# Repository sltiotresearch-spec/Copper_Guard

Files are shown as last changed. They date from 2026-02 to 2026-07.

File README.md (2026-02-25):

# 🛡️Copper_Guard
Copper Guard is an IoT-based copper cable protection system that detects wire cuts or failures and instantly sends SMS and call alerts using ESP12F (ESP8266) and SIM800C GSM module.

When a wire is cut or disabled:
- 📩 An SMS alert is sent
- 📞 A phone call notification is triggered

The system evolved through four hardware versions, improving scalability, connectivity, and reliability.

---

## 🚀 Versions Overview

| Version | Image | Wires Supported | Board Type | Connectivity | Deployment |
|---|---|---|---|---|---|
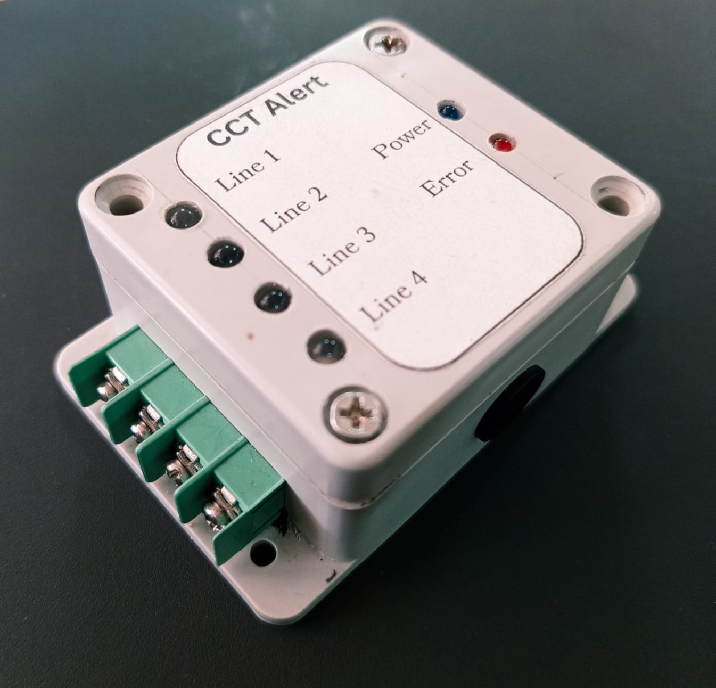
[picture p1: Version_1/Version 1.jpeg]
| Version 1 |  | 4 | STEM Board | GSM | Prototype |
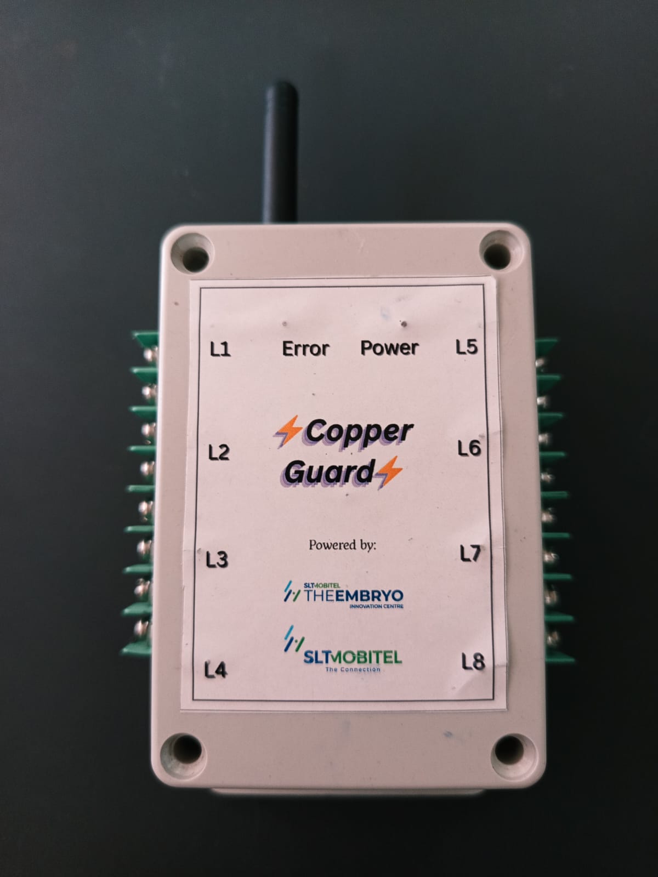
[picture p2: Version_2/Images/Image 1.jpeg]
| Version 2 |  | 8 | ESP Board | GSM + WiFi | 5 devices |
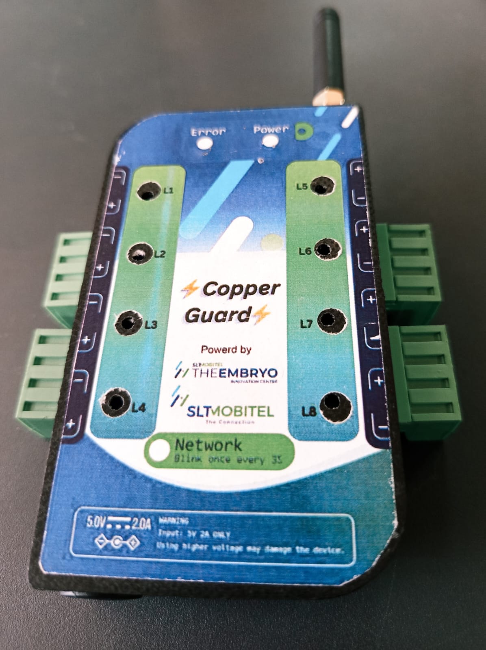
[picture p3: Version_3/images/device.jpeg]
| Version 3 |  | 8 | Custom PCB | GSM + WiFi | Improved |
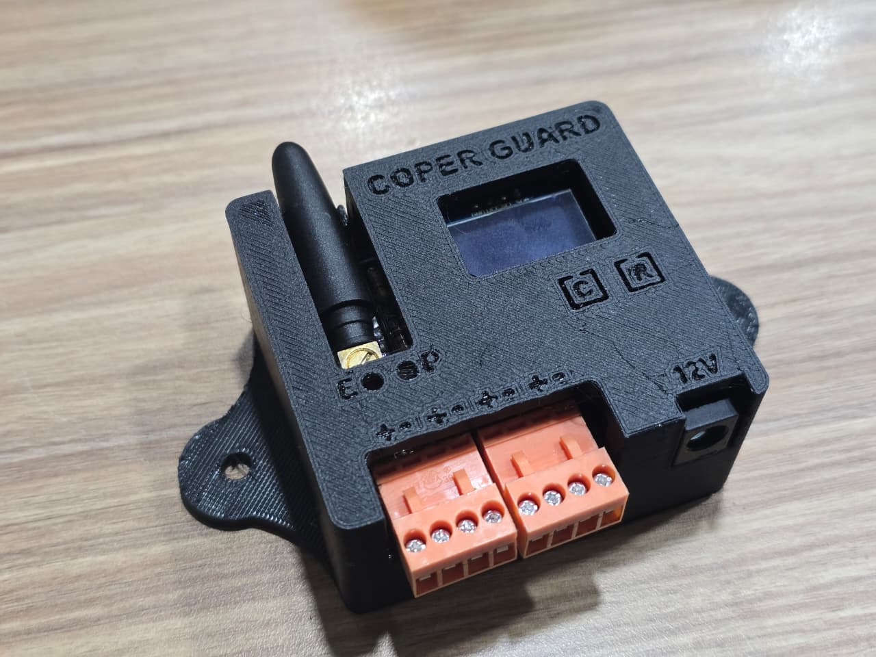
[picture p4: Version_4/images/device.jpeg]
| Version 4 |  | 4 | Custom PCB + ESP12F | GSM + WiFi + OLED | Junction |
---

## 🔧 System Features

- Wire cut detection using optocouplers
- SMS and Call alert system
- GSM communication module
- Buck converter power regulation
- WiFi connectivity (ESP versions)
- OLED display (Version 4)

---

## 📂 Branch Structure

Each version is maintained in a separate branch:

- `version1`
- `version2`
- `version3`
- `version4`

Each branch contains:
- Source code
- PCB design files
- Schematics
- Photos
- Documentation

---

## 📍 Deployment

Version 2 devices are currently deployed in the Ratnapura district.

---

## 👨‍💻 Author

Developed as part of Copper Guard Project.

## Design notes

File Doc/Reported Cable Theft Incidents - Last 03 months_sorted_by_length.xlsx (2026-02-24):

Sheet: Sheet2
Row Labels | Count of LEA | Sum of Length (m)
BIA | 22 | 892
GQ | 22 | 1391
VR | 18 | 1172
KOM | 18 | 1260
RN | 14 | 1013
AW | 10 | 500
MGM | 10 | 1130
KY | 10 | 440
KWL | 10 | 1925
AD | 9 | 472
MNG | 9 | 1225
VG | 8 | 835
MAL | 8 | 401
KT | 8 | 640
BG | 7 | 795
PUG | 7 | 370
MLT | 6 | 1850
DJ | 6 | 950
KDW | 6 | 305
AB | 6 | 573
DX | 6 | 387
PW | 5 | 600
WJ | 5 | 335
KEL | 5 | 450
PK | 5 | 300
BW | 5 | 360
KLY | 4 | 205
PNG | 4 | 320
GIR | 4 | 245
KDY | 3 | 595
GE | 3 | 300
HO | 3 | 386
KAL | 3 | 220
MI | 3 | 555
KR | 2 | 250
KWA | 2 | 342
PE | 2 | 150
RG | 2 | 52
PL | 2 | 155
SL | 2 | 150
GLG | 2 | 185
JL | 2 | 12
RAM | 2 | 260
KDL | 2 | 180
RM | 2 | 170
MMU | 2 | 192
UDT | 2 | 180
DGD | 2
GP | 2 | 160
NC | 2 | 130
EH | 2 | 98
WT | 2 | 20
HZ | 1 | 230
RKL | 1 | 80
GU | 1 | 80
KWN | 1 | 200
DI | 1 | 200
AG | 1
MX | 1 | 245
KG | 1 | 50
RK | 1 | 100
PTR | 1 | 20
AK | 1 | 50
WP | 1 | 200
MNA | 1 | 100
KJ | 1 | 120
MWI | 1 | 30
HAR | 1 | 680
KE | 1 | 70
HEY | 1 | 65
RGM | 1 | 50
DG | 1 | 80
MH | 1 | 150
(blank) |  | 1833
Grand Total | 329 | 30716

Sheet: Sheet1
Region | Province | OPMC | LEA | Incident Date (m,d) | Location | Length (m)
REGION 01 | CP | KY | KY | 2024-11-30 | Gamunu Mawatha Jnc, Hanthana | 15
METRO | METRO 02 | RM | RM | 2025-01-01 | Maha Vihara Rd, Moratuwa | 20
REGION 02 | SP | MH | WJ | 2025-01-03 | Sathyahettige mawatha - Weligama | 160
REGION 01 | WPN | NTB | VG | 2025-01-05 | Eksath Mawatha Marapola Nywala | 200
REGION 02 | SP | MH | AK | 2025-01-05 | Near Athuraliya Maha Vidyalaya ground, Akuressa rd, Athuraliya | 50
REGION 01 | WPN | NTB | KDY | 2025-01-06 | Kotadeniyawa Walpita Farm Road | 200
REGION 02 | WPS | KT | MGM | 2025-01-06 | Peragas junction, Pelawatta Rd | 160
REGION 02 | SAB & UVA | KE | GLG | 2025-01-06 | Nelundeniya Allauwa Road | 140
REGION 02 | SP | MH | WJ | 2025-01-06 | Warakapitiya-Welihinda road 500m before the junction to CBL(munchee) warehouse . | 100
REGION 02 | WPS | KT | MGM | 2025-01-07 | Malwathukanda Road, Horawala | 150
REGION 02 | WPS | KT | MGM | 2025-01-07 | Malwathukanda Road, Horawala | 150
REGION 02 | SP | MH | KJ | 2025-01-08 | Near the Archeology Office on Kamburupitiya - Kadduwa Road | 120
REGION 01 | WPN | NG | MNG | 2025-01-10 | Aluthapola, Minuwangoda | 150
REGION 01 | WPN | KI | MAL | 2025-01-10 | Ulahitiwala | 70
REGION 01 | WPN | NTB | VG | 2025-01-13 | Balabowa Sadun uyana Road (Balabowa Ambalama) | 160
REGION 01 | WPN | NG | MNG | 2025-01-17 | Develapola, Minuwangoda | 150
METRO | METRO 02 | HO | KOM | 2025-01-18 | Meegahawatta Rd, Kanampella,Kosgama | 31
REGION 02 | WPS | KT | KT | 2025-01-20 | Meneri Thenna Road near Saw mill | 500
REGION 02 | SAB & UVA | RN | KEL | 2025-01-20 | Kiriella - Madala | 120
REGION 02 | SAB & UVA | RN | BG | 2025-01-25 | Balangoda,Amupitiya Near Mamalgaha Juntion | 250
REGION 02 | WPS | KT | MGM | 2025-01-25 | Delgas junction, Madawala Road | 231
REGION 01 | WPN | NTB | KDY | 2025-01-25 | Kotadeniyawa Walpita Farm Road | 180
REGION 02 | SAB & UVA | KE | MNA | 2025-01-25 | Daswaththa | 100
REGION 02 | SAB & UVA | RN | KEL | 2025-01-28 | Kiriella-Madala | 150
REGION 01 | NWP | KLY | PL | 2025-01-29 | Paragammana - Ingaradawla Road - infront of Dummalapitiya watta | 75
REGION 01 | WPN | GQ | GQ | 2025-01-30 | Balummahara Junction Miriswatta, Gampaha | 95
REGION 01 | WPN | GQ | GQ | 2025-02-01 | Balummahara Junction Miriswatta, Gampaha | 75
REGION 01 | WPN | GQ | GE | 2025-02-02 | Kothalawala mw | 110
REGION 01 | WPN | GQ | GE | 2025-02-02 | Kothalawala mw | 100
REGION 01 | WPN | NG | MNG | 2025-02-02 | Galoluwa | 65
REGION 01 | WPN | GQ | GQ | 2025-02-04 | Balummahara Junction Miriswatta, Gampaha | 50
REGION 01 | NWP | KG | AB | 2025-02-05 | Narammala Road,Maharachchimulla./Humbuluwa Alawwa | 120
REGION 01 | NWP | KG | AB | 2025-02-05 | Narammala Road,Maharachchimulla./Humbuluwa Alawwa | 80
REGION 01 | WPN | KI | VR | 2025-02-05 | Ahugammana | 45
REGION 01 | WPN | NG | MNG | 2025-02-06 | Yakahatuwa | 300
REGION 01 | WPN | GQ | GQ | 2025-02-06 | Balummahara Junction Miriswatta, Gampaha | 50
REGION 02 | SAB & UVA | KE | RK | 2025-02-07 | Thaldawa- Rambukkana | 100
REGION 01 | WPN | GQ | GE | 2025-02-07 | Rajasinghe mw | 90
REGION 02 | WPS | KT | MGM | 2025-02-08 | Kalupahana road Peragas junction. | 90
REGION 01 | WPN | KI | VR | 2025-02-08 | Maharagama | 50
REGION 02 | WPS | KT | MGM | 2025-02-09 | Pelawaththa road Peragas junction. | 95
REGION 01 | WPN | GQ | GQ | 2025-02-10 | Balummahara Junction Miriswatta, Gampaha | 50
REGION 01 | WPN | KI | MAL | 2025-02-13 | Wewa pARA, Mapitigama | 120
REGION 01 | WPN | KI | VR | 2025-02-13 | Danawkanda rd Kirikittha | 87
REGION 01 | WPN | KI | MAL | 2025-02-13 | Kanukatiya | 60
REGION 01 | NWP | KG | AB | 2025-02-14 | COLOMBO RD,KAPUWARALA,ALAWWA. | 98
REGION 01 | NWP | KG | PW | 2025-02-14 | WADAKADA RD,UDAPOLA,POLGAHAWELA. | 80
REGION 01 | NWP | KG | PW | 2025-02-14 | WADAKADA RD,UDAPOLA,POLGAHAWELA. | 80
METRO | METRO 02 | HO | KOM | 2025-02-15 | Pahathgama Junction | 130
REGION 01 | NWP | KG | AB | 2025-02-16 | HITHTHARAPOLA,MAHARACHCHIMULLA,ALAWWA. | 85
REGION 01 | WPN | NG | DJ | 2025-02-21 | Niwala road Wewagedara | 130
REGION 01 | NWP | KG | PW | 2025-02-21 | Narammala Road,udapola & Narammala Road, Wadakada,Polgahawela | 120
REGION 01 | NWP | KLY | PL | 2025-02-21 | Werahara Road , Yakwila - infront of wewa | 80
REGION 01 | NWP | KG | PW | 2025-02-21 | Narammala Road,udapola & Narammala Road, Wadakada,Polgahawela | 80
REGION 01 | NWP | KG | AB | 2025-02-21 | Giriulla Road,7 mile post,paramaulla,Alawwa. | 40
REGION 01 | WPN | KI | KDW | 2025-02-22 | Mankda Paara | 60
REGION 01 | WPN | NG | DJ | 2025-02-25 | Hirikuluwa road Badalgama | 270
REGION 01 | WPN | NTB | MI | 2025-02-25 | Bothele Madagama Adupe Road | 150
REGION 01 | WPN | KI | KDW | 2025-02-27 | Mankda Paara | 60
REGION 01 | WPN | KI | KDW | 2025-02-27 | Mankda Paara | 60
REGION 03 | EP | VA | MMU | 2025-02-27 | Mamaduwa main road | 50
REGION 02 | SAB & UVA | RN | BG | 2025-03-01 | Imbulpe | 80
REGION 01 | WPN | NTB | VG | 2025-03-02 | Dadagamuwa Temple Road Veyangoda | 220
REGION 03 | NP | VA | MMU | 2025-03-03 | Mamaduwa main road | 142
REGION 01 | NWP | KLY | KLY | 2025-03-04 | Narangalla - Wadugedara rd (near to paddy fied ) | 75
REGION 01 | NWP | KLY | KLY | 2025-03-04 | Narangalla - Wadugedara rd (near to paddy fied ) | 75
REGION 02 | SAB & UVA | RN | BG | 2025-03-04 | Rassagala Road | 60
REGION 01 | NWP | KLY | KLY | 2025-03-04 | Hettipola rd - Hediyamulla ( Near to Helabojunhala) | 40
REGION 01 | NWP | KLY | KLY | 2025-03-04 | Hettipola rd - Hediyamulla ( Near to Helabojunhala) | 15
REGION 01 | WPN | NTB | MI | 2025-03-05 | Warakapola road Thalagama | 270
REGION 01 | NWP | CW | MX | 2025-03-11 | Uraliya-Panirendawa Road, Sembukattiya | 245
REGION 01 | WPN | KI | VR | 2025-03-11 | Batahena Kanatta near Kirikitta Road | 20
REGION 01 | WPN | KI | VR | 2025-03-11 | Batahena Kanatta near Kirikitta Road | 20
REGION 01 | WPN | KI | VR | 2025-03-11 | Batahena Kanatta near Kirikitta Road | 20
REGION 01 | WPN | NTB | KAL | 2025-03-13 | Galamuna Hapitigama Kaleliya | 70
REGION 01 | WPN | NTB | KAL | 2025-03-16 | Galamuna Hapitigama Kaleliya | 40
REGION 03 | NP | AD | KWA | 2025-03-18 | Madatugama A9 road | 196
REGION 01 | WPN | WT | WT | 2025-03-18 | Bangalawatta road, Wattala | 10
REGION 01 | WPN | WT | WT | 2025-03-18 | Bangalawatta road, Wattala | 10
REGION 01 | WPN | KI | VR | 2025-03-19 | Godagedara temple Road ,Balummahara | 105
REGION 01 | WPN | KI | VR | 2025-03-19 | Godagedara temple Road ,Balummahara | 105
REGION 03 | NP | AD | MWI | 2025-03-19 | Issinbessagala, Medawachchiya | 30
REGION 01 | NWP | KLY | HZ | 2025-03-22 | Hettipola moragolla - near to moragolla wewa | 230
REGION 03 | NP | AD | KWA | 2025-03-22 | Madatugama A9 road | 146
METRO | METRO 01 | KX | KDL | 2025-03-22 | Near jalthara Tile factory | 100
REGION 01 | WPN | NTB | VG | 2025-03-23 | Magalegoda Bemmulla Road | 40
REGION 01 | WPN | NTB | VG | 2025-03-24 | Magalegoda Bemmulla Road | 70
REGION 01 | CP | GP | GP | 2025-03-25 | Dolsabage Road,Sinhapitiya | 80
METRO | METRO 02 | HO | KOM | 2025-03-25 | Kaluaggala Labugama Rd, Near transformer | 50
REGION 01 | WPN | KI | BIA | 2025-03-27 | Dekatana Jambugas Handiya | 40
REGION 01 | WPN | KI | BIA | 2025-03-27 | Dekatana Jambugas Handiya | 40
Region 01 | WPN | NTB | VG | 2025-03-29 | Keenawala Koshena watta road | 60
Region 01 | WPN | NTB | KDY | 2025-03-31 | Kotadeniyawa Walpita Farm Road | 215
REGION 01 | CP | GP | GP | 2025-04-01 | Mawathura, Gampola | 80
REGION 01 | WPN | KI | BIA | 2025-04-02 | Pattihandiya near bridge | 3
Region 01 | WPN | WT | JL | 2025-04-03 | Kristhraja Mawatha, Thudalla, JaELA | 6
REGION 01 | WPN | KI | BIA | 2025-04-05 | Kelaniya OPMC | 64
REGION 01 | WPN | NG | DJ | 2025-04-06 | Ethiliyagala Road, Balagalla | 200
REGION 02 | SAB & UVA | RN | BG | 2025-04-06 | Kirimatitenna near Senaka Pole Yard | 175
REGION 01 | WPN | NG | DJ | 2025-04-06 | Ethiliyagala Road, Balagalla (4 core fiber cable) | 150
REGION 02 | SAB & UVA | RN | BG | 2025-04-06 | Meddekanda - Rassagala Road | 80
REGION 02 | SAB & UVA | RN | BG | 2025-04-06 | Vikiliya, Kalthota road near Ape Kade Hardware in Balangoda | 70
REGION 01 | WPN | WT | RG | 2025-04-06 | Prison Rd, Samagi Mawatha.Ragama | 40
REGION 01 | WPN | KI | KWL | 2025-04-07 | Meethirigala | 85
REGION 01 | WPN | GQ | GQ | 2025-04-07 | Grama sanwardhena mw, Oruthota | 80
REGION 01 | WPN | GQ | UDT | 2025-04-09 | Kahatowita | 80
REGION 01 | WPN | KI | BIA | 2025-04-09 | Kanukatiya | 60
Region 01 | WPN | NTB | MI | 2025-04-12 | Idiparape Road Mirigama | 135
REGION 01 | WPN | KI | BIA | 2025-04-12 | Mapiltigama | 70
REGION 01 | WPN | KI | BIA | 2025-04-12 | Near Ambalama | 60
REGION 01 | WPN | KI | BIA | 2025-04-14 | Putupagala | 70
REGION 02 | SAB & UVA | RN | BG | 2025-04-15 | Weligepola road at Damahana in Balangoda | 80
REGION 02 | SAB & UVA | RN | KEL | 2025-04-17 | Kurugammodara,Heraniyawaka-Matuwagala bus hlt | 40
METRO | METRO 02 | HO | PNG | 2025-04-19 |  | 25
REGION 02 | SAB & UVA | RN | EH | 2025-04-23 | Cable theft at Minnana area | 58
REGION 01 | WPN | KI | BIA | 2025-04-27 | Putupagala | 80
REGION 01 | NWP | KLY | GU | 2025-04-29 | Haddamulla junction Giriulla | 80
REGION 01 | WPN | NG | MNG | 2025-04-30 | Mathammana Walawwa Road | 150
REGION 01 | WPN | NG | MNG | 2025-04-30 | Mathammana Walawwa Road | 150
REGION 01 | WPN | NG | MNG | 2025-04-30 | Mathammana Walawwa Road | 150
Region 01 | WPN | NTB | VG | 2025-05-02 | Mahavita Junction Yakkala | 35
REGION 02 | SAB & UVA | RN | RN | 2025-05-03 | Cable Theft at Thiriwanaketiya Juntion | 100
REGION 01 | WPN | KI | BIA | 2025-05-10 | Pidaliwatta | 85
REGION 02 | SAB & UVA | RN | RN | 2025-05-14 | Cable theft at Malwala Road - Dimbulvitiya | 250
METRO | METRO 02 | RM | RM | 2025-05-15 | Angulana, Saumya Pedesa | 150
REGION 02 | SAB & UVA | RN | PE | 2025-05-15 | Sannasgama Pelmadulla | 120
REGION 02 | SP | MH | MH | 2025-05-17 | Near Rassandeniya Juntion,Dondra | 150
REGION 02 | SAB & UVA | RN |  | 2025-05-17 | Nivithigala Watapotha Road Ambalandeniya case-1 | 120
REGION 01 | WPN | KI | BIA | 2025-05-17 | Putupagala | 100
REGION 02 | SAB & UVA | RN | KR | 2025-05-19 | Kuruwita Eratne Road | 150
REGION 01 | WPN | KI | BIA | 2025-05-21 | Putupagala | 80
REGION 02 | SAB & UVA | RN |  | 2025-05-21 | Nivithigala Watapotha Road Ambalandeniya case-2 | 40
REGION 02 | SAB & UVA | RN | EH | 2025-05-21 | Minnana Near Wikasitha Garage | 40
REGION 02 | SAB & UVA | RN | RN | 2025-05-23 | Cable theft incident at Thiriwanaketiya Juntion | 50
REGION 02 | SAB & UVA | RN | RN | 2025-05-24 | Gonakumbura Road | 150
REGION 02 | SAB & UVA | RN |  | 2025-05-24 | Nivithigala Watapotha Road Ambalandeniya case-3 | 120
Region 01 | WPN | NTB | KAL | 2025-05-25 | Kukulnape Road Pallewela | 110
METRO | METRO 02 | HO | KOM | 2025-05-25 | Labugama Rd | 25
METRO | METRO 02 | HO | KOM | 2025-05-25 | Labugama Rd | 25
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

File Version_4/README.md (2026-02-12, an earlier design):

# 🛡️ Copper Guard – Version 4

> Optimized 4-Channel Monitoring System  
> Integrated PCB Design | GSM + WiFi + OLED

---

## 📌 Overview

Copper Guard Version 4 is the optimized and refined version of the system, designed specifically for 4-way cross road installations.

Unlike previous versions supporting 8 wires, Version 4 is intentionally limited to 4 wires, as a standard 4-way junction requires monitoring of only four copper lines.

This version integrates the ESP12F chip directly onto a custom PCB and includes an OLED display for real-time system status monitoring.

---

## 🚀 Key Improvements Over Version 3

- Optimized from 8 wires → 4 wires (junction-specific design)
- Integrated **ESP12F chip** directly on PCB
- Added **OLED display** for live system feedback
- Cleaner and more compact PCB layout
- Dedicated GSM board with antenna
- Reduced hardware complexity

---

## 🔧 Hardware Components

- 📡 GSM Board with Antenna
- 🌐 ESP12F WiFi Chip (Integrated on PCB)
- 🔌 4 Optocouplers
- ⚡ Buck Converter
- 🖥 OLED Display
- 🖨 Custom Designed PCB

---

## ⚙️ System Specifications

| Feature | Description |
|---|---|
| Wire Capacity | 4 Wires |
| Communication | GSM + WiFi |
| Alert System | SMS + Phone Call |
| Display | OLED Status Display |
| Power Regulation | Buck Converter |
| Isolation Method | Optocouplers |
| Design Type | Fully Integrated Custom PCB |

---

## 🧠 Working Principle

1. Each of the 4 copper lines is connected through an optocoupler for isolation.
2. The ESP12F continuously monitors line status.
3. If a wire is cut or disabled:
   - 📩 SMS alert is sent via GSM module
   - 📞 Phone call notification is triggered
4. The OLED display shows:
   - Line status
   - System state
   - Connectivity information
5. WiFi connectivity allows future IoT expansion or monitoring.

---

## 📂 Folder Structure
````
version4
│
├── firmware
│ ├── main.ino
│ └── libraries.txt
│
├── hardware
│ ├── schematic.pdf
│ ├── pcb_layout.pdf
│ └── gerber_files
│
├── Images
│ ├── pcb_top.jpg
│ ├── pcb_bottom.jpg
│ ├── assembled_unit.jpg
│ └── oled_display.jpg
│
└── README.md
````
---

## 📡 Communication Architecture
````
Copper Wire Inputs (4 Lines)
│
▼
Optocouplers (Isolation Stage)
│
▼
ESP12F (Main Controller)
│
├──► GSM Board
│ ├── SMS Alert
│ └── Phone Call Alert
│
├──► OLED Display
│ └── Real-Time Status Display
│
└──► WiFi Network
└── Remote Monitoring (Optional)
````
---

## 🌍 Deployment Design Context

Version 4 is designed specifically for:

- 4-way road junction installations
- Compact field deployment
- Reduced hardware overhead
- Improved maintainability

Since a standard 4-way cross road only requires monitoring of 4 copper lines, supporting 8 wires is unnecessary.  
Version 4 removes excess complexity while improving integration.

---

## ⚠️ Limitations

- Limited to 4 wire inputs (junction-specific)
- Requires stable GSM signal for reliable alerting
- WiFi functionality depends on network availability

---

## 🔮 System Evolution Summary

| Version | Key Change |
|---|---|
| V1 | Basic GSM prototype (4 wires) |
| V2 | Expanded to 8 wires + WiFi |
| V3 | Custom PCB implementation |
| V4 | Integrated ESP12F + OLED + Optimized 4-wire design |

---

## 🛠 Installation Overview

1. Connect 4 copper lines to input terminals.
2. Power the system through regulated supply.
3. Insert configured SIM card into GSM board.
4. Configure alert numbers in firmware.
5. Verify OLED display for system status.
6. Test by simulating wire disconnection.

---

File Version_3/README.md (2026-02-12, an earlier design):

# 🛡️ Copper Guard – Version 3

> 8-Channel Copper Wire Monitoring System  
> Custom PCB Implementation | GSM + WiFi Enabled

---

## 📌 Overview

Copper Guard Version 3 is an improved hardware refinement of Version 2.

The core functionality remains the same:
- 8 wire monitoring
- GSM alert system
- WiFi connectivity via ESP board

The major improvement in Version 3 is the transition from a dot board assembly to a custom-designed PCB, significantly improving reliability, structure, and maintainability.

---

## 🚀 Improvements Over Version 2

- Replaced dot board with **custom PCB**
- Reduced wiring complexity
- Improved circuit stability
- Better mechanical strength
- Cleaner and more professional hardware layout

---

## 🔧 Hardware Components

- 📡 GSM Module
- 🌐 ESP Board (WiFi enabled)
- 🔌 8 Optocouplers
- ⚡ Buck Converter
- 📶 External Antenna
- 🖥 Custom Designed PCB

---

## ⚙️ System Specifications

| Feature | Description |
|---|---|
| Wire Capacity | 8 Wires |
| Communication | GSM + WiFi |
| Alert System | SMS + Phone Call |
| Power Regulation | Buck Converter |
| Isolation Method | Optocouplers |
| Board Type | Custom PCB |

---

## 🧠 Working Principle

1. Each copper wire line is connected through an optocoupler.
2. The ESP board continuously monitors the status of all 8 lines.
3. If a wire is cut or disabled:
   - 📩 The GSM module sends an SMS alert
   - 📞 A phone call notification is triggered
4. WiFi connectivity allows remote monitoring or IoT expansion.

---

## 📂 Folder Structure
````
version3
│
├── firmware
│ ├── main.ino
│ └── libraries.txt
│
├── hardware
│ ├── schematic.png
│ └── gerber_files
│
├── Images
│ └── device.jpeg
│
└── README.md
````
---

## 📡 Communication Architecture
````
Copper Wire Inputs (8 Lines)
│
▼
Optocouplers (Isolation Stage)
│
▼
ESP Board (Controller)
│
├──► GSM Module
│ ├── SMS Alert
│ └── Phone Call Alert
│
└──► WiFi Network
└── Remote Monitoring (Optional)
````
---

## 🌍 Deployment Context

Version 3 represents the transition from prototype-level hardware to a more production-ready design.

The use of a custom PCB:
- Improves long-term durability
- Simplifies assembly
- Reduces electrical noise
- Enhances maintainability

---

## ⚠️ Limitations

- Requires stable GSM signal for reliable alerting
- Depends on WiFi availability for remote monitoring
- Still limited to 8 wire inputs

---

## 🔮 Evolution Path

Version 3 paved the way for:
- Integrated ESP12F chip on PCB (Version 4)
- OLED status display
- Optimized 4-wire configuration for junction installations

---

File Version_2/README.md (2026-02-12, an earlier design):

# 🛡️ Copper Guard – Version 2

> Expanded 8-Channel Copper Wire Monitoring System  
> GSM + WiFi Enabled | Field Deployed Model

---

## 📌 Overview

Copper Guard Version 2 is an improved and expanded version of the original copper wire monitoring system.

This version:
- Increases wire capacity  
- Introduces WiFi connectivity  
- Improves system flexibility using an ESP-based board  

📍 **Five devices are currently deployed in the Ratnapura District.**

---

## 🚀 Key Improvements from Version 1

- Increased wire capacity from **4 → 8**
- Replaced STEM board with **ESP board**
- Added **WiFi connectivity**
- Improved scalability
- Field deployment of **5 devices**
- Dot board implementation for component connections

---

## 🔧 Hardware Components

- 📡 GSM Module (for SMS and Call alerts)
- 🌐 ESP Board (WiFi enabled)
- 🔌 8 Optocouplers (for wire monitoring)
- ⚡ Buck Converter (Voltage regulation)
- 📶 External Antenna
- 🧩 Dot Board (Prototype board assembly)

---

## ⚙️ System Specifications

| Feature | Description |
|---|---|
| Wire Capacity | 8 Wires |
| Communication | GSM + WiFi |
| Alert System | SMS + Phone Call |
| Power Regulation | Buck Converter |
| Isolation Method | Optocouplers |
| Deployment | 5 Active Units |

---

## 🧠 Working Principle

1. Each copper wire line is connected through an optocoupler.  
2. The ESP board continuously monitors the status of all 8 lines.  
3. If a wire is cut or disabled:
   - 📩 The GSM module sends an SMS alert  
   - 📞 A phone call notification is triggered  
4. WiFi connectivity allows remote monitoring or future IoT integration.

---

## 📂 Folder Structure
````
version2
│
├── firmware
│ ├── main.ino
│ └── libraries.txt
│
├── Images
│ ├── Image 1.jpeg
│ ├── Image 2.jpeg
│ └── Image 3.jpeg
│
└── README.md

````
---

## 📡 Communication Architecture
````
Wire Input
↓
Optocoupler
↓
ESP Board
├── GSM Module → SMS + Call
└── WiFi Network → Remote Monitoring (Optional)

````
---

## 🌍 Deployment Information

- **Location:** Ratnapura District  
- **Units Installed:** 5  
- **Environment:** Roadside / Field installations  
- **Status:** Operational  

---

## ⚠️ Limitations

- Built using dot board (not custom PCB)
- Manual assembly increases wiring complexity
- Requires stable GSM signal for reliable alerting

---

## 🔮 Future Improvements (Implemented in Later Versions)

- Custom PCB design (Version 3)
- Integrated ESP12F chip on PCB (Version 4)
- OLED status display (Version 4)
- Optimized wire capacity for junction-based installations

---

## 🛠 Installation Overview

1. Connect 8 copper lines to input terminals.  
2. Power the system via regulated supply (through buck converter).  
3. Insert configured SIM card into GSM module.  
4. Connect ESP to WiFi network (if remote monitoring required).  
5. Configure alert phone numbers in firmware.  
6. Deploy and test by simulating wire disconnection.

---

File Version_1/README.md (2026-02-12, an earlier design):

# Copper Guard - Version 1

## 📌 Overview
Version 1 is the initial prototype of Copper Guard.

## 🔧 Hardware Components

- GSM Module
- 4 Optocouplers
- Buck Converter
- STEM Board
- DIP Switch
- PCB Type Antenna

## ⚙️ Features

- Supports 4 wire connections
- DIP switch to enable/disable wires
- SMS and Call alert system
- GSM-based communication

## ⚠️ Limitations

- SIM number must be changed when DIP switch configuration changes
- Only one device built

## 📂 Folder Structure

- firmware → Arduino code
- hardware → Schematics and PCB
- images → Device images
- documentation → System explanation

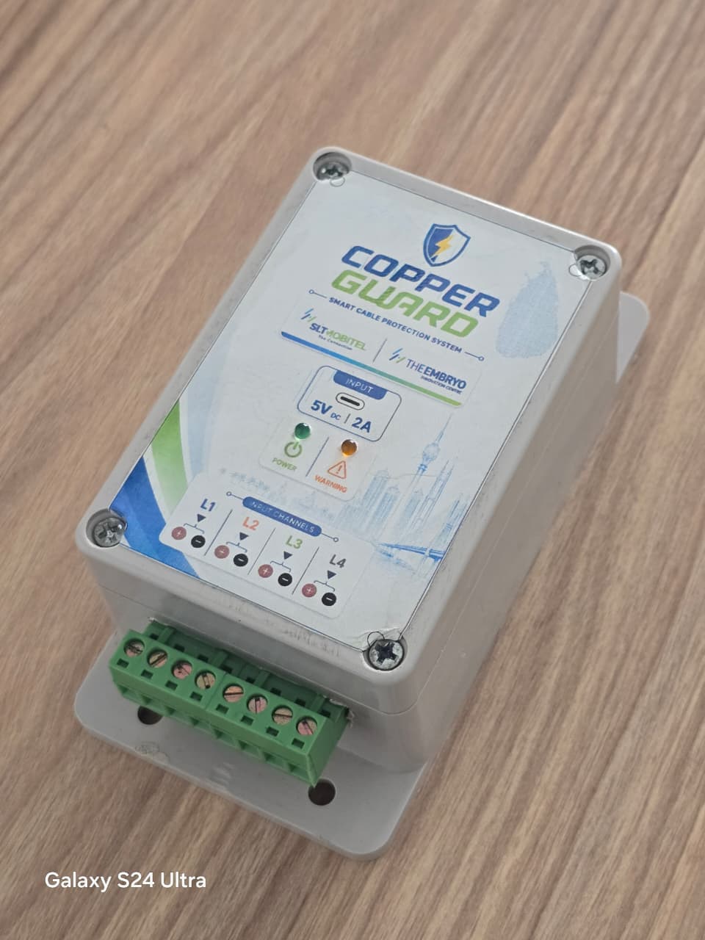
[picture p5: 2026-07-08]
Version_5/Images/WhatsApp Image 2026-06-15 at 12.03.02 PM.jpeg

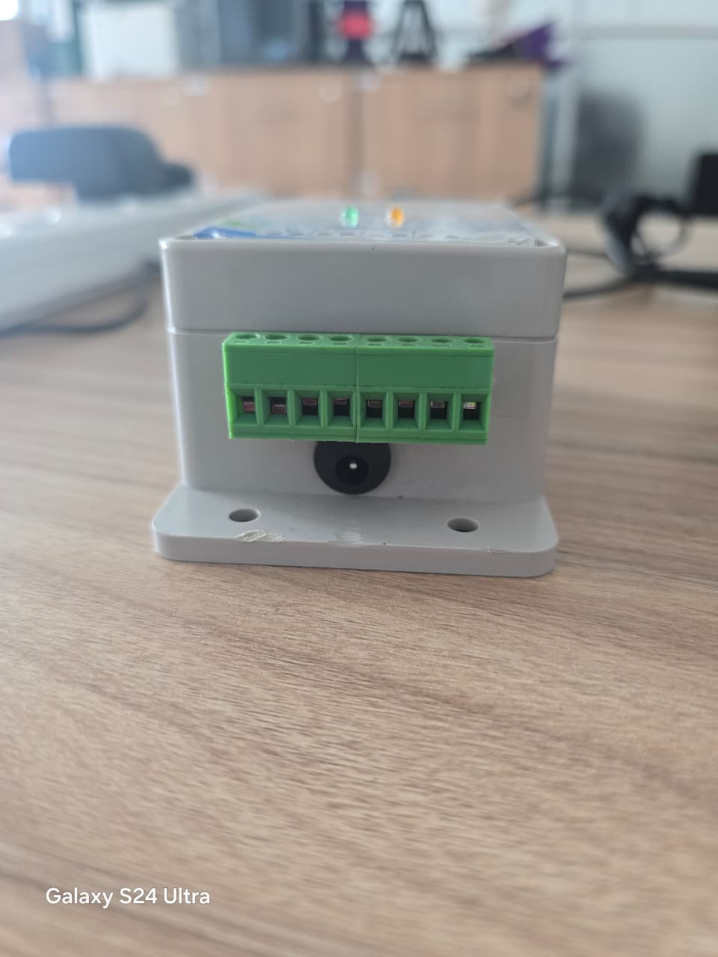
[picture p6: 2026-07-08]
Version_5/Images/WhatsApp Image 2026-06-15 at 12.05.35 PM.jpeg

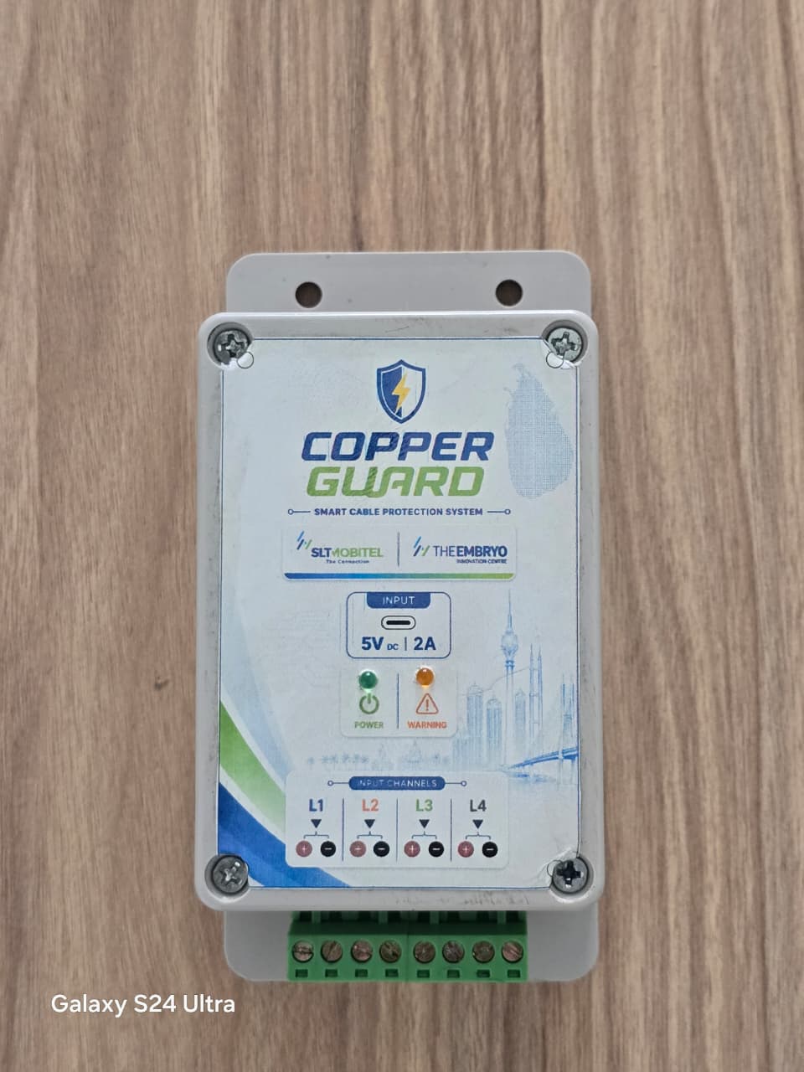
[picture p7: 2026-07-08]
Version_5/Images/WhatsApp Image 2026-06-15 at 12.03.03 PM.jpeg

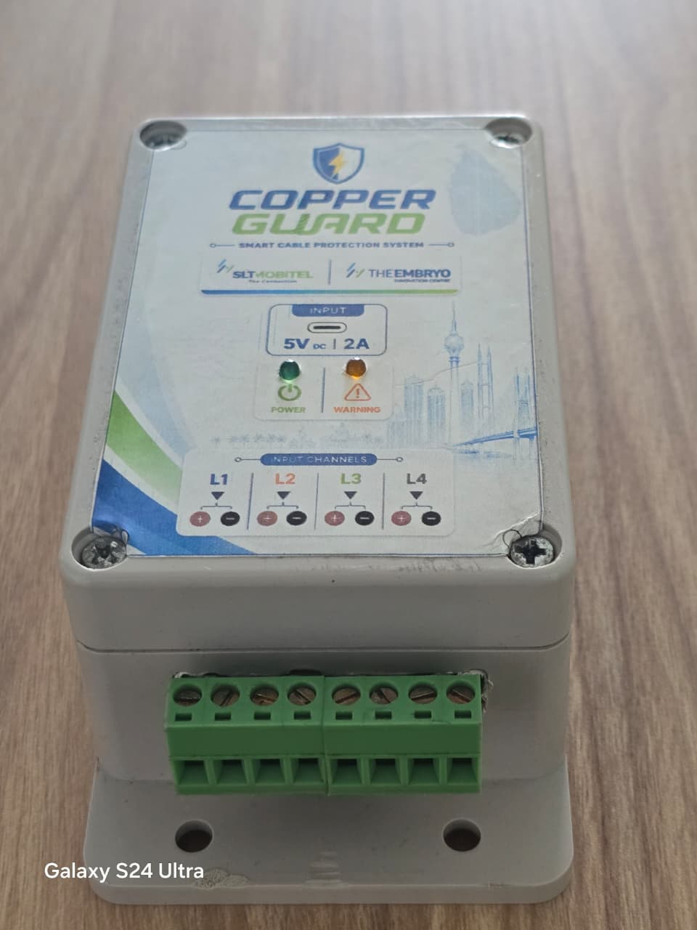
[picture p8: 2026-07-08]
Version_5/Images/WhatsApp Image 2026-06-15 at 12.03.04 PM.jpeg

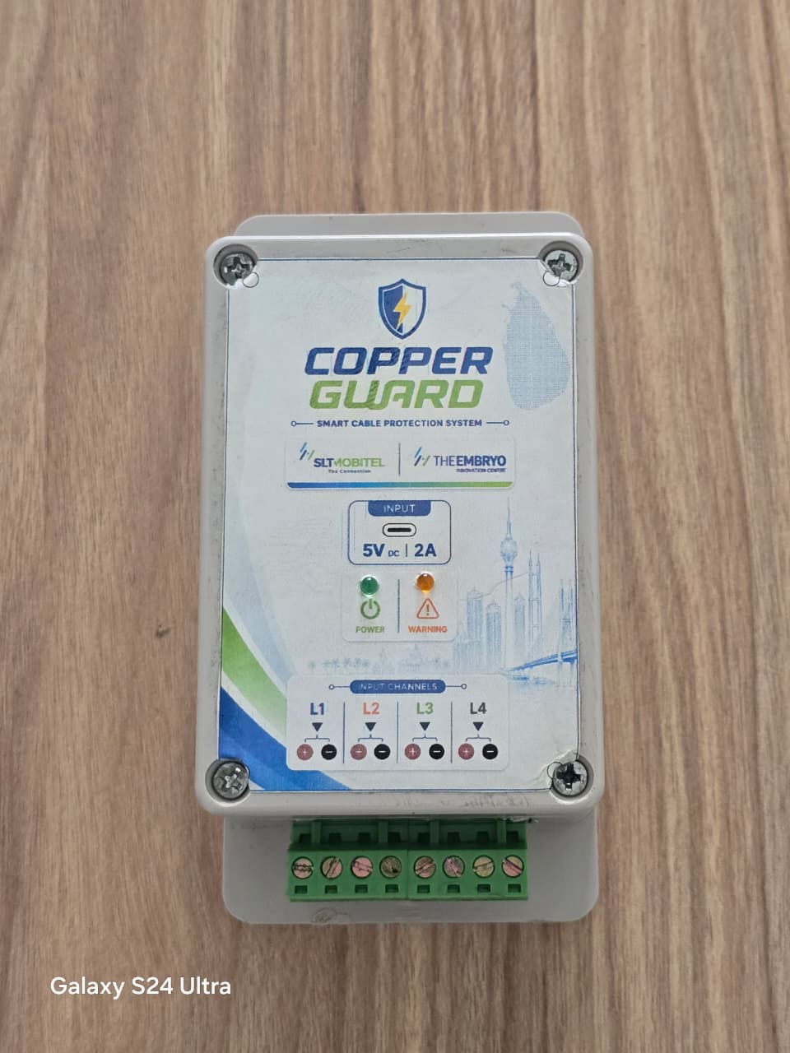
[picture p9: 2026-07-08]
Version_5/Images/WhatsApp Image 2026-06-15 at 12.03.00 PM.jpeg

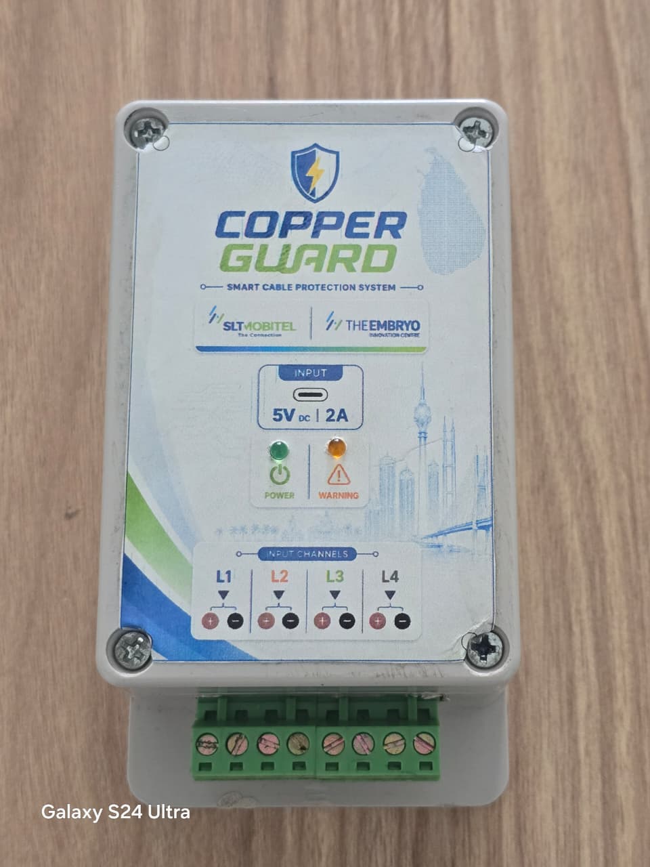
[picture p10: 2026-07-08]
Version_5/Images/WhatsApp Image 2026-06-15 at 12.03.01 PM.jpeg

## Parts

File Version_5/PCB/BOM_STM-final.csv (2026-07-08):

ID | Name | Designator | Footprint | Quantity | Manufacturer Part | Manufacturer | Supplier | Supplier Part | Price
1 | 4.7kΩ | R1,R2,R3,R4 | R2512 | 4 | 25121WJ0472T4E | UNI-ROYAL(厚声) | LCSC | C33178 | 0.023
2 | 3.3kΩ | R5,R6,R7,R8 | R1210 | 4 | RC1210FR-073K3L | YAGEO(国巨) | LCSC | C83146 | 0.025
3 | B2B-PH-K-S(LF)(SN) | CN1 | CONN-TH_B2B-PH-K-S | 1 | B2B-PH-K-S(LF)(SN) | JST | LCSC | C131337 | 0.035
4 | B8B-PH-K-S-(LF)(SN) | U1 | CONN-TH_B8B-PH-K-S-LF-SN | 1 | B8B-PH-K-S(LF)(SN) | JST | LCSC | C157974 | 0.096
5 | B4B-PH-K-S-(LF)(SN) | U3,U4 | CONN-TH_B4B-PH-K-S-LF-SN | 2 | B4B-PH-K-S-(LF)(SN) | JST Sales America | LCSC | C160257
6 | Header-Female-2.54_1x10 | J1,J2 | HDR-TH_10P-P2.54-V-F | 2 | 2.54-1*10P母 | BOOMELE(博穆精密) | LCSC | C35445 | 0.107
7 | ic socket 16 pin | OPTOCOUPLER | DIP-16_L20.3-W10.2-P2.54-LS7.6-BL | 1 | X5621FV-2x08-C762D7430 | XKB Connectivity(中国星坤) | LCSC | C2684758 | 0.526
8 | 10kΩ | R9,R10 | R1206 | 2 | 1206W4J0103T5E | UNI-ROYAL(厚声) | LCSC | C1489 | 0.006

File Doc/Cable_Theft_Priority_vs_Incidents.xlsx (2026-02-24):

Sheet: Priority_vs_Incidents
OPMC | Priority Node | Mapped LEA (base) | Incidents in last 3 months (same OPMC & LEA) | Total stolen length (m) | Max single incident length (m) | First incident date | Last incident date
KE | MNA-DSW-NODE | MNA | 1 | 100 | 100 | 2025-01-25 | 2025-01-25
KE | MNA-KPP-NODE | MNA | 1 | 100 | 100 | 2025-01-25 | 2025-01-25
RN | BG-IBP-NODE | BG | 7 | 795 | 250 | 2025-01-25 | 2025-04-15
RN | RN-GKB-NODE | RN | 14 | 1013 | 250 | 2025-05-03 | 2025-11-06
BD | BD-WRP-NODE | BD | 0 | 0
BD | MM-LNG-NODE | MM | 0 | 0

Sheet: Matched_Incidents
Region | Province | OPMC | LEA | Incident Date (m,d) | Location | Copper Cable Type | Unnamed: 7 | Length (m) | GPS (From) | GPS (To) | Police Entry No. | Reported Date (mm/dd/yyyy) | No of affected Customers | Failure Duration(hours) | Estimated Value of Stolen Cables (LKR) | Cost of Replacemnt (LKR) | WO Status | Unnamed: 18 | Unnamed: 19 | Unnamed: 20 | Matched priority nodes
REGION 02 | SAB & UVA | RN | BG | 2025-01-25 | Balangoda,Amupitiya Near Mamalgaha Juntion | Aerial | 0.9MM/50PR | 250 | 6.678343 80.736550 | 6.680223 80.737630 | MOIB 65/50 |  |  |  | 191304.2 |  | SAP81193 | 2025-01-27 | 2025-09-30 | Approved | BG-IBP-NODE
REGION 02 | SAB & UVA | RN | RN | 2025-05-14 | Cable theft at Malwala Road - Dimbulvitiya | Aerial | 0.5MM/100PR | 250 | 6.715561 80.441674 | 6.714161 80.440535 | GCIB (1) 82/124 | 2025-05-14 |  |  | 663474.12 |  | SAP83921 | 2025-05-19 |  | Approved | RN-GKB-NODE
REGION 02 | SAB & UVA | RN | BG | 2025-04-06 | Kirimatitenna near Senaka Pole Yard | Aerial | 0.65MM/150PR | 175 | 6.630489, 80.728140 | 6.630113, 80.729701 | MOIB 180/59 | 2025-04-07 |  |  | 301237.03 |  | SAP83326 | 2025-04-19 |  | Approved | BG-IBP-NODE
REGION 02 | SAB & UVA | RN | RN | 2025-05-24 | Gonakumbura Road | Aerial | 0.5MM/100PR | 150 | 6.6720506 80.4651694 | 6.6709664 80.4661813 | GCIB (02) 138/225 | 2025-05-24 |  |  | 403883.27 |  | SAP84116 | 2025-05-28 |  | Approved | RN-GKB-NODE
REGION 02 | SAB & UVA | RN | RN | 2025-06-19 | Malwala Road Incident - 2 | Aerial | 0.5MM/100PR | 112 | 6.73085 80.43520 | 6.73152 80.43516 | MOIB 258/67 | 2025-06-20 |  |  | 303194.46 |  | SAP84912 | 2025-06-25 |  | Approved | RN-GKB-NODE
REGION 02 | SAB & UVA | KE | MNA | 2025-01-25 | Daswaththa | Aerial | 0.5MM/10PR | 100 | 7.223274,80.441287 |  | GCIB 63/556 |  |  |  | 120784.83 |  | SAP82072 | 2025-02-27 |  | Approved | MNA-DSW-NODE, MNA-KPP-NODE
REGION 02 | SAB & UVA | RN | RN | 2025-05-03 | Cable Theft at Thiriwanaketiya Juntion | Aerial | 0.5MM/150PR | 100 | 6.665665 80.431985 | 6.665542 80.432909 | GCIB(02)354/36 | 2025-05-04 |  |  | 281212.61 |  | SAP83822 | 2025-05-15 |  | Approved | RN-GKB-NODE
REGION 02 | SAB & UVA | RN | RN | 2025-06-19 | Malwala Road Incident - 1 | Aerial | 0.5MM/100PR | 91 | 6.72519 80.43947 | 6.72462 80.44000 | GCIB C(1) 106/232 | 2025-06-20 |  |  | 245508.44 |  | SAP84909 | 2025-06-25 |  | Approved | RN-GKB-NODE
REGION 02 | SAB & UVA | RN | BG | 2025-04-15 | Weligepola road at Damahana in Balangoda | Aerial | 0.9MM/50PR | 80 | 6.608817 80.736963 | 6.609219 80.737105 | MOIB 370/208 | 2025-04-22 |  |  | 144333.49 |  | SAP83393 | 2025-04-22 |  | Approved | BG-IBP-NODE
REGION 02 | SAB & UVA | RN | BG | 2025-04-06 | Meddekanda - Rassagala Road | Aerial | 0.65MM/50PR | 80 | 6.676198, 80.671349 | 6.676199, 80.671342 | MOIB 179/58 | 2025-04-07 |  |  | 134542.26 |  | SAP83311 | 2025-04-17 |  | Approved | BG-IBP-NODE
REGION 02 | SAB & UVA | RN | BG | 2025-03-01 | Imbulpe | Aerial | 0.9MM/50PR | 80 | 6.678343 80.736550 | 6.680223 80.737630 | MOIB 171/57 | 410961 |  |  | 161304.25 |  | SAP82221 | 2025-03-04 | 2025-09-30 | Approved | BG-IBP-NODE
REGION 02 | SAB & UVA | RN | BG | 2025-04-06 | Vikiliya, Kalthota road near Ape Kade Hardware in Balangoda | Aerial | 0.65MM/30PR | 70 | 6.624958, 80.741966 | 6.625300, 80.742509 | MOIB 220/90 | 2025-04-09 |  |  | 98347.02 |  | SAP83327 | 2025-04-19 |  | Approved | BG-IBP-NODE
REGION 02 | SAB & UVA | RN | BG | 2025-03-04 | Rassagala Road | Aerial | 0.65MM/100PR | 60 | 6.661998 80.692571 | 6.662205, 80.692181 | MOIB 214/35 | 2025-03-04 |  |  | 160963.17 |  | SAP82249 | 2025-03-04 | 2025-09-30 | Approved | BG-IBP-NODE
REGION 02 | SAB & UVA | RN | RN | 2025-05-27 | Berenduwa Road | Aerial | 0.65MM/100PR | 50 | 6.663714 80.483289 | 6.63399 80.482976 | GCIB (1) 204/198 | 2025-05-27 |  |  | 132123.1 |  | SAP84119 | 2025-05-28 |  | Approved | RN-GKB-NODE
REGION 02 | SAB & UVA | RN | RN | 2025-05-23 | Cable theft incident at Thiriwanaketiya Juntion | Aerial | 0.5MM/150PR | 50 | 6.665640 80.431484 | 6.665886 80.431077 | GCIB (2) 129/211 | 2025-05-23 |  |  | 165957.36 |  | SAP84010 | 2025-05-23 |  | Approved | RN-GKB-NODE
REGION 02 | SAB & UVA | RN | RN | 2025-06-21 | Thiriwanaketiya Juntion | Aerial | 0.5MM/80PR | 50 | 6.66571 80.43214 | 6.665551 80.4330264 | G(1) 152/283 | 2025-06-25 |  |  | 76158.76 |  | SAP84918 | 2025-06-25 |  | Approved | RN-GKB-NODE
REGION 02 | SAB & UVA | RN | RN | 2025-06-19 | Thiriwanaketiya Juntion | Aerial | 0.5MM/80PR | 50 | 6.665690, 80.432608 | 6.66571 80.43214 | GCIB(2) 107/220 | 2025-06-19 | 50 |  | 54549.32 |  | SAP84888 | 2025-06-24 |  | Approved | RN-GKB-NODE
REGION 02 | SAB & UVA | RN | RN | 2025-09-19 | Marapana,R'pura | Aerial | 0.9MM/50PR | 40 | 6.6516 80.4427 | 6.65188 80.4423 | P (1) 96/144 | 2025-09-22 |  |  | 111035.01 |  | SAP87329 | 2025-09-24 |  | Approved | RN-GKB-NODE
REGION 02 | SAB & UVA | RN | RN | 2025-09-02 | RN~PN Road Near 65/3 Culvert | Aerial | 0.5MM/100PR | 40 | 6.696011 80.375849 | 6.696064 80.375409 | P(3) 19/26 | 2025-09-03 |  |  | Rs.132,286.61 |  | SAP86811 | 2025-09-04 |  | Approved | RN-GKB-NODE
REGION 02 | SAB & UVA | RN | RN | 2025-11-06 | karangoda Juntion Ratnapura | Aerial | 0.5MM/100PR | 30 | 6.6640 80.3811 | 6.663723 80.380853 | MOIB 289/27 | 2025-11-08 |  |  | 131616.21 |  | SAP88800 | 2025-11-11 |  | Approved | RN-GKB-NODE
REGION 02 | SAB & UVA | RN | RN | 2025-05-20 | Thiriwanaketiya~Kalawana Road near bridge around 200m | Aerial | 0.5MM/150PR |  | 6.662266 80.433554 | 6.662266 80.433554 | P(6) 23/89 | 2025-05-20 |  |  | 28532.2 |  | SAP84009 | 2025-05-23 |  | Approved | RN-GKB-NODE
REGION 02 | SAB & UVA | RN | RN | 2025-07-13 | Pelwadiya,Ratnapura | Aerial |  |  | 6.663785, 80.446460 | Same | P-01 233/139.13.05 | 2025-07-14 |  |  | 55604.12 |  | SAP85480 | 2025-07-15 |  | Approved | RN-GKB-NODE

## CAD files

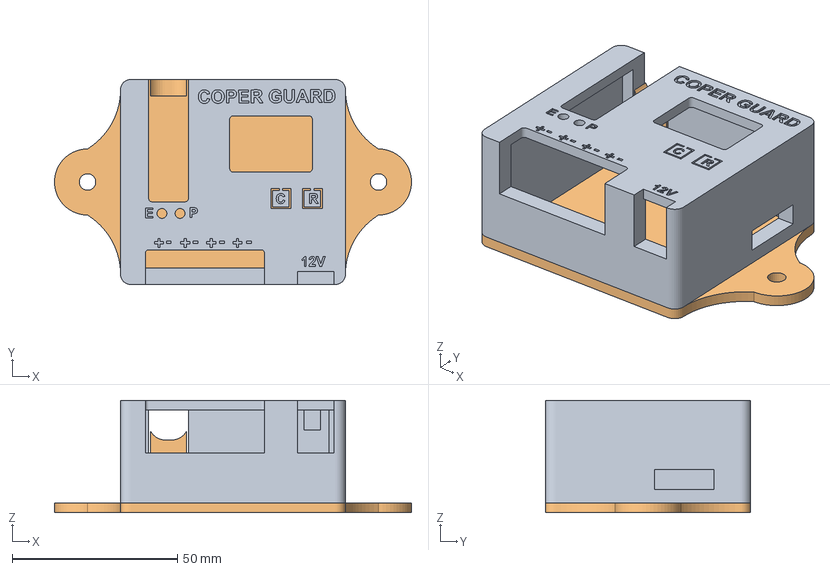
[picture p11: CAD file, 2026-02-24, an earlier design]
Version_4/3D_model/v4_new.3mf
108.0 x 62.0 x 34.0 mm

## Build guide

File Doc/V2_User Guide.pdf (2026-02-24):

# User Manual

# Copper Guard

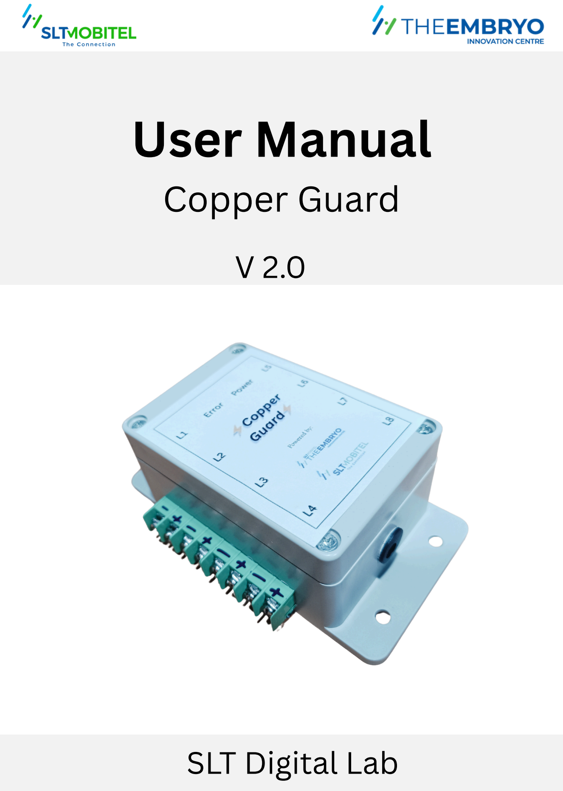
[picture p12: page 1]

# SLT Digital Lab

V 2.0

## Introduction

## Package Contents

## Device Overview

## Installation Instructions

## Configuration and Setup

## Operation

## Maintenance and Troubleshooting

## Safety Information

## Warranty and Support

## Technical Specifications

# Table of Contents

----------------------------------------- 01

--------------------------------- 02

--------------------------------- 03

------------------------- 04

------------------------- 05

------------------------- 06

-------------- 07

------------- 08

----------------------------- 09

--------------------------- 10

# Introduction

## The CopperGuard is a compact, IoT-based copper cable theft alerting device designed to monitor up to 8 copper power lines carrying 48V DC. Built with an ESP32 microcontroller, 8 optocoupler channels, a SIM800L GSM module, and a 3A buck converter, the device continuously

checks the integrity of each monitored line.

If any line is cut or tampered with, CopperGuard immediately sends an SMS alert to preconfigured mobile numbers, helping facility managers or utility providers respond quickly and prevent loss or downtime. The device is powered by a stable 5V 2A input and connects easily using screw terminal blocks for secure and reliable

installation.

## CopperGuard is ideal for applications such as telecom towers, solar farms, street lighting systems, and industrial

setups where copper theft can cause serious disruption.

# Package Contents

## Copper Guard Device

## Power Adapter

x 1

x 1

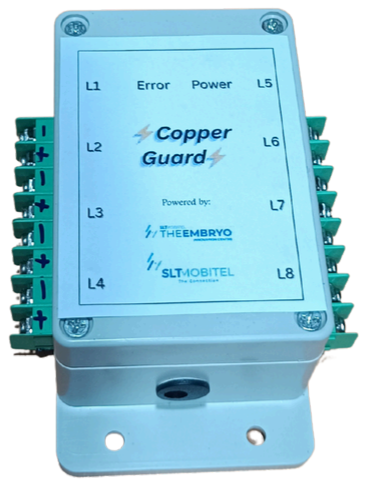
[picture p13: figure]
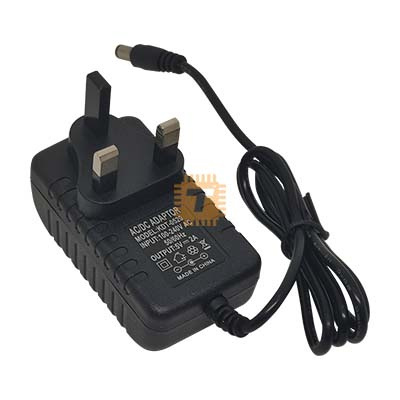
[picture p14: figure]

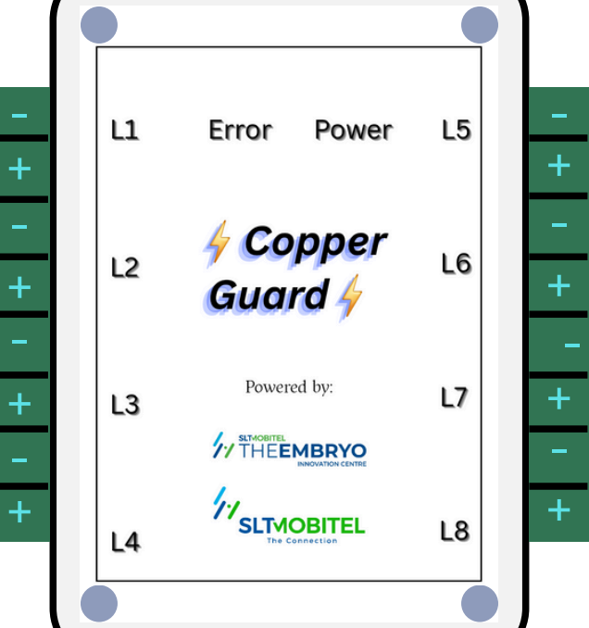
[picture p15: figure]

2

# Device Overview

1

3

## 1.Configuration Mode Button 2.Phone Line Connectors 3.Power Input

Step 1: Physical Installation

1.Mounting the Device:
Use the provided flange clamps on the enclosure to secure the device to a wall, pole, or control panel using screws.
Ensure the enclosure is placed in a dry and protected environment to avoid exposure to water or corrosive substances.
2. Wiring the Copper Lines:
Connect each copper cable (48V DC lines) to the screw terminals labeled L1 to L8.
Follow polarity markings (+/-) carefully.
Only connect the lines you want to monitor. Others can be disabled in software.

# Installation Instructions

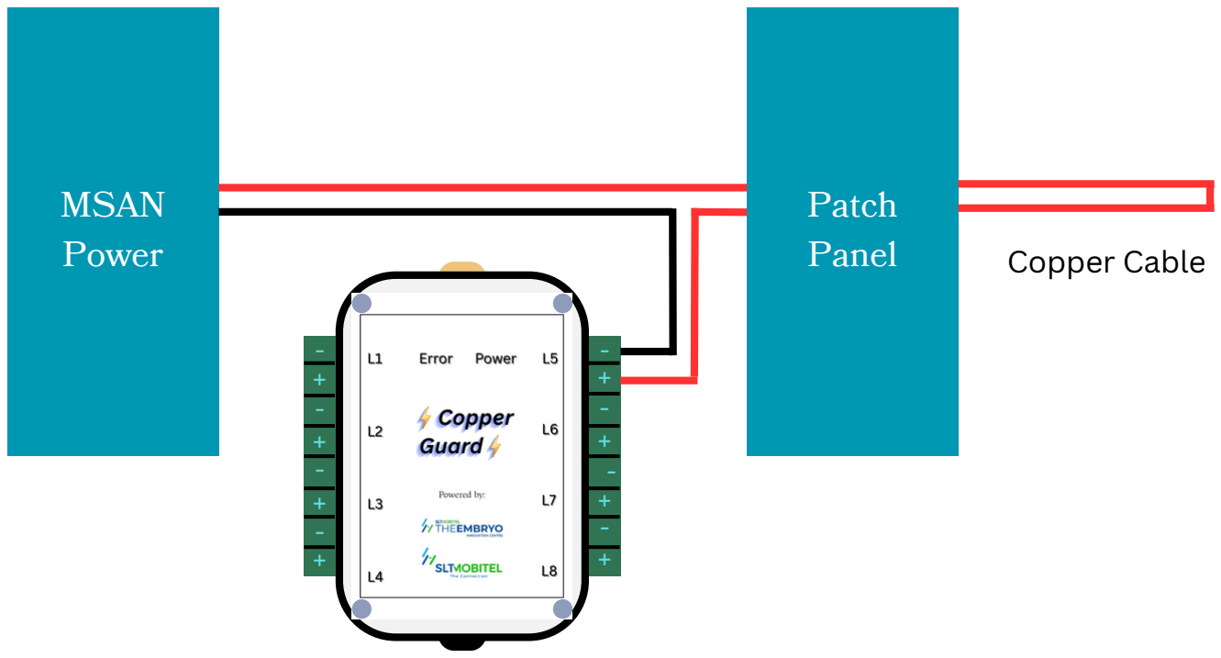
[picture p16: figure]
MSAN Power; Patch Panel; Copper Cable

3. Powering the Device:
Supply a regulated 5V 2A power input using a DC barrel jack (as shown in your image).
Do not power on yet—proceed to configuration first.
Step 2: First-Time Configuration

⚠️ IMPORTANT: First-time setup must be done before normal operation.

Enter Configuration Mode:
Press and hold the configuration mode button (connected to GPIO 21). While holding the button, connect the power to the device.
Release the button once the device powers up.

Connect to Device Hotspot:
The device will create a Wi-Fi Access Point (AP) named: CCT

_

Alert

_

Device

_

XXXX
Where XXXX is your device index (e.g., test device may show CCT_Alert_Device_0008).
Use a mobile or laptop to connect to this AP using the password: 0001digital
Access Configuration Page:
Open a browser and visit: http://192.168.1.1
You'll see the configuration UI (as shown in the screenshots).

Device Name

Location

Status SMS

Emergency Alert

Status SMS Interval (Minutes)

Line 1–8

Custom name to identify this unit (e.g., Tower B North)

Physical location (e.g., Colombo 01)

Recipients Comma-separated mobile numbers to receive regular status updates
(e.g.,

+94750279306,

+94753124128)

Recipients Comma-separated numbers to alert when a line is cut

How often to send status updates (e.g., 1 = every minute)

Toggles Enable or disable individual copper line monitoring. Green means active.

Field | Description

# Fill in the Configuration Form:

# Configuration and Setup

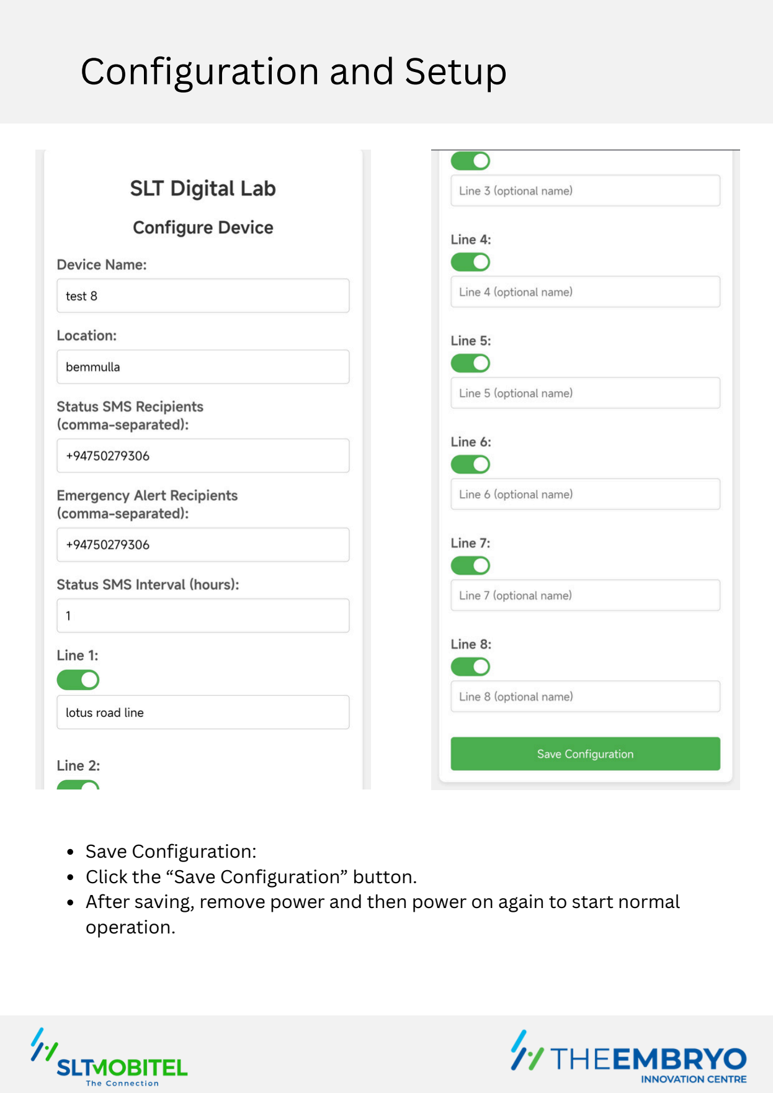
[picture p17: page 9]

Save Configuration:
Click the “Save Configuration” button.
After saving, remove power and then power on again to start normal operation.

# Normal Operation

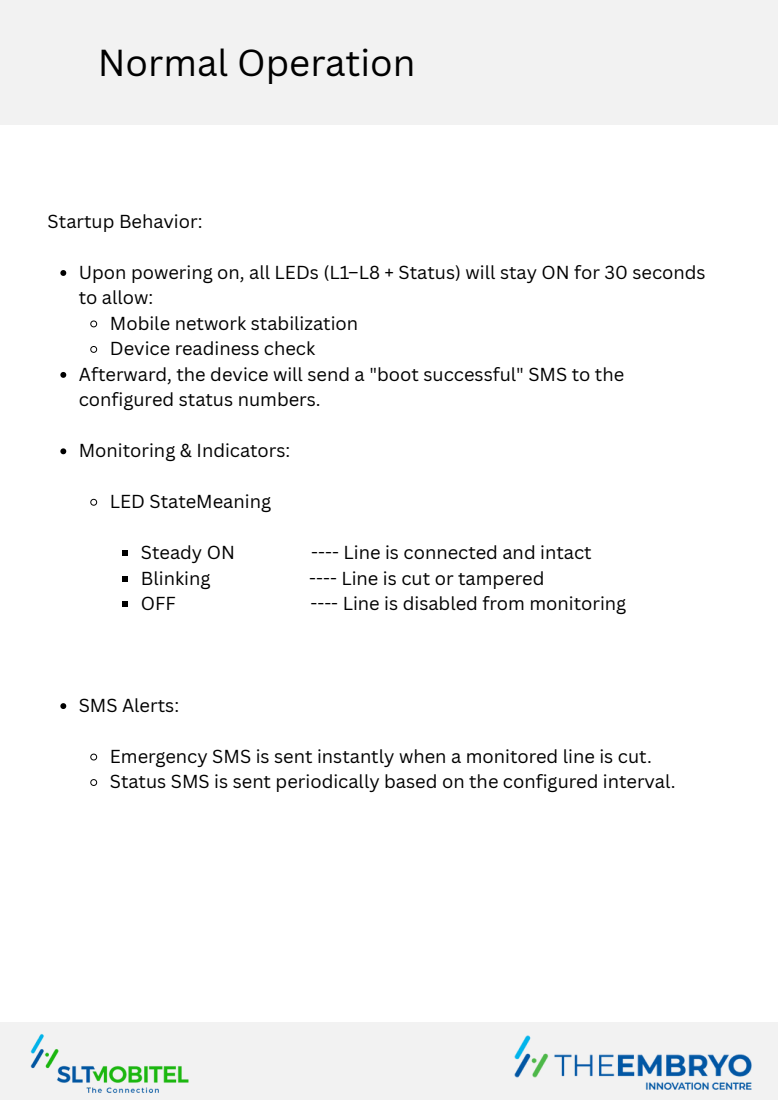
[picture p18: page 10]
Startup Behavior:; Monitoring & Indicators:; LED StateMeaning; Steady ON; ---- Line is connected and intact; Blinking; ---- Line is cut or tampered; OFF; ---- Line is disabled from monitoring; SMS Alerts:

Upon powering on, all LEDs (L1–L8 + Status) will stay ON for 30 seconds
to allow:
Mobile network stabilization
Device readiness check
Afterward, the device will send a "boot successful" SMS to the
configured status numbers.

Emergency SMS is sent instantly when a monitored line is cut.
Status SMS is sent periodically based on the configured interval.

# Normal Operation

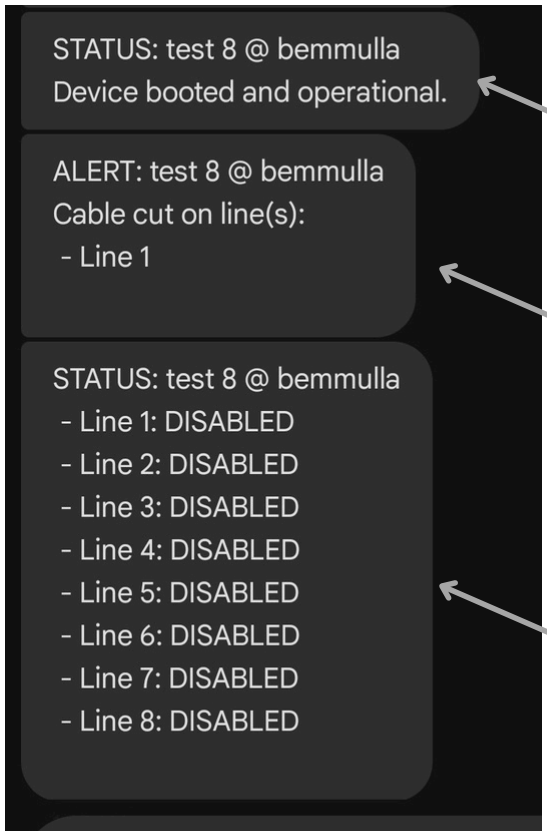
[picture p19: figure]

1

2

3

## 1.Device boot message 2.Line cut alert message 3.Status message

# Maintenance and Troubleshooting

Routine Maintenance

Perform the following checks monthly or as part of preventive maintenance routines:

Task | Description
Visual Inspection | Check the enclosure for physical damage, corrosion, or water ingress.
Wiring Check | Ensure all terminal screws are tight and copper lines are properly seated.
LED Indicator Check | Verify all enabled line LEDs are steady ON (not blinking or off).
Power Supply | Confirm 5V 2A regulated supply is stable and connector is firmly attached.
Status SMS Verification | Check if scheduled status SMS messages are being received as expected.

# Maintenance and Troubleshooting

Troubleshooting Scenarios

1. No LEDs Turn ON at Startup Possible Causes:
No power to the device
Faulty power supply
Internal damage or short
Action:
Check 5V adapter and cable
Use a multimeter to verify voltage at the barrel input Replace adapter if faulty
2. SIM800L Not Responding / No SMS Sent Possible Causes:
Weak mobile signal
SIM not registered to network
Action:
Move device to location with better signal
3. LED for a Monitored Line is Blinking Continuously Meaning: Line is detected as cut or tampered Action:
Physically inspect the copper line wiring
Check for loose connections or damaged cable If it's a false alert, verify voltage at line terminals
4. Configuration Mode Not Working Possible Causes:
Button not functioning
Not held before applying power Action:
Hold the button while connecting power

# Maintenance and Troubleshooting

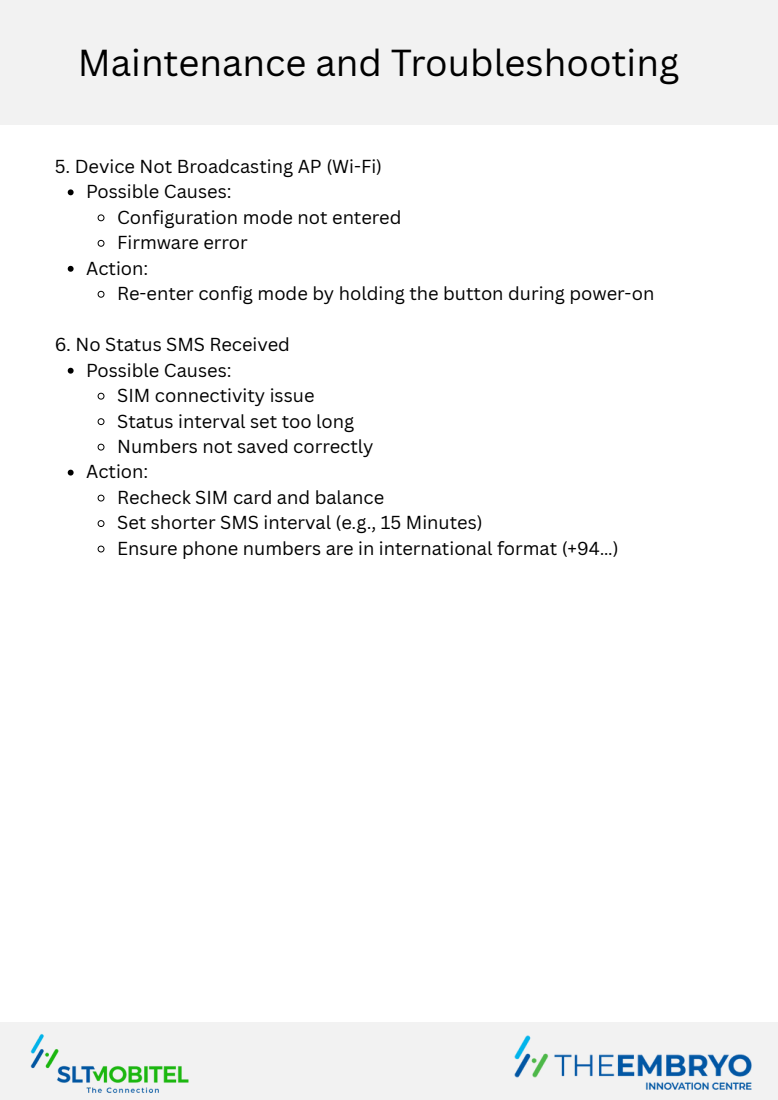
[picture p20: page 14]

5. Device Not Broadcasting AP (Wi-Fi)
Possible Causes:
Configuration mode not entered
Firmware error
Action:
Re-enter config mode by holding the button during power-on

6. No Status SMS Received
SIM connectivity issue
Status interval set too long
Numbers not saved correctly
Recheck SIM card and balance
Set shorter SMS interval (e.g., 15 Minutes)
Ensure phone numbers are in international format (+94…)

# Technical Specifications

Core Components:

Microcontroller Unit:
Model: ESP32
Function: Hosts firmware logic, manages line monitoring, SMS communication, and configuration modes.
Features: Dual-core processor, Wi-Fi , low power consumption.

Line Monitoring Interface:
Type: 8-Channel Optocoupler Array
Voltage Handling: Optimized for 48V DC detection
Function: Provides galvanic isolation and real-time line status input to the ESP32.

Communication Module:
Model: SIM800L GSM Module
Function: Sends SMS alerts upon detection of a line cut or system heartbeat status update.
SIM Support: Micro SIM
Network: Quad-band GSM (850/900/1800/1900 MHz)

Power Supply:
Input Voltage: 5V DC (regulated), supplied via 5V 2A adapter
Internal Conversion: Integrated 3A buck converter to power ESP32, SIM800L, and optocouplers
Power Resilience: Designed for continuous operation in harsh environments

Connectivity:
Wiring Interface: Screw terminal blocks (pluggable) for all 8 monitored lines and power input
Indicator LEDs: Status indication for power, SIM connectivity, and each line channel

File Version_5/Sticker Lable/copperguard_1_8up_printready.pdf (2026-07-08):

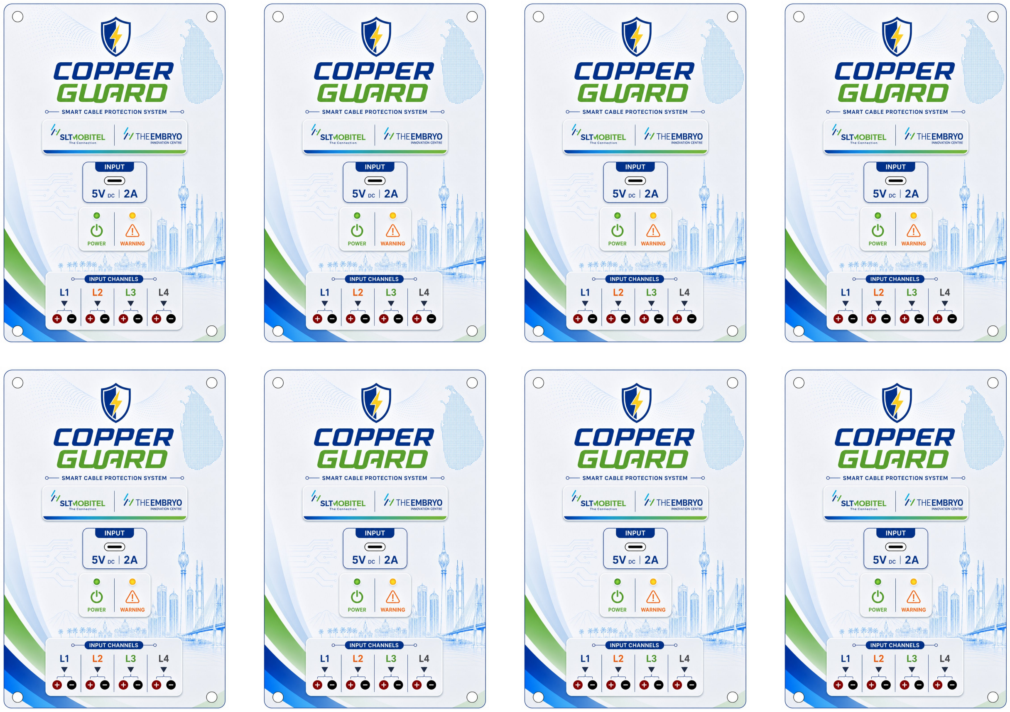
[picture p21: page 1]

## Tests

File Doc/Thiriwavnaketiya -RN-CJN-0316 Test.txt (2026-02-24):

Thiriwavnaketiya -RN-CJN-0316 Test Unit 0703936209
https://maps.app.goo.gl/GSSDYsqewjtYU3Jw7

Marapana -RN-MPN-0307
Https://maps.app.goo.gl/919Xmy4dUPbpLKxt5

Gonakubura-RN-GKB-0308
+94 70 452 0094
Https://maps.app.goo.gl/iYnuoHxsTPdoAtfD8

Panagama-NA-PNG-0302 +94704452187 
https://maps.app.goo.gl/CZbmCjYdd6QRKaH28

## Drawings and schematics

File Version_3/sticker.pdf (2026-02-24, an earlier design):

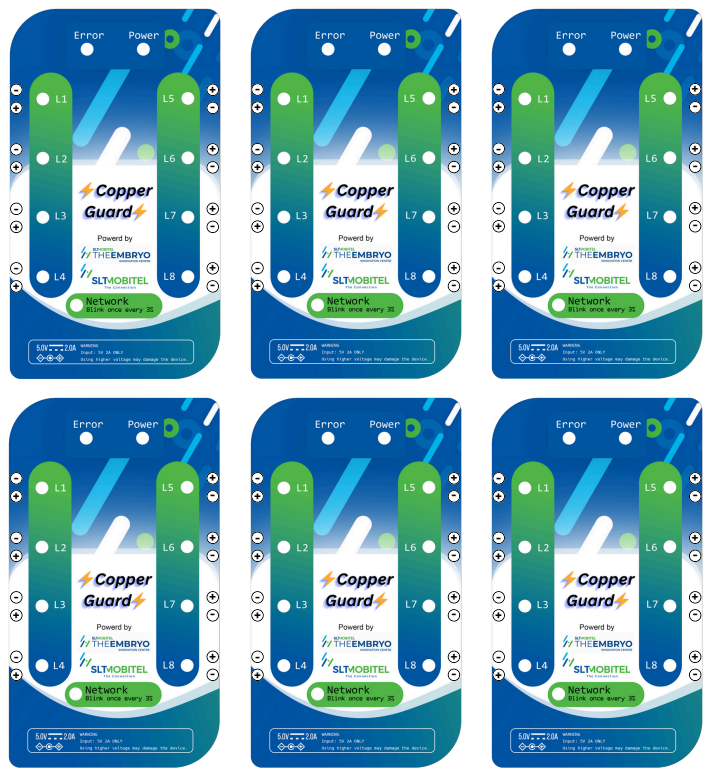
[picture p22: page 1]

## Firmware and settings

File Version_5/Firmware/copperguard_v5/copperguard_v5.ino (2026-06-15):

#include <string.h>

// =====================================================
// Copper Guard
// AT OK + Network OK continuous check
// Incoming SMS configuration from registered number only
// Send alert SMS when enabled line is CUT
// =====================================================

// ---------------- DEFAULT CONFIG ----------------
// These values can be changed later using SMS:
// +94750279306,Colombo 01 ABC,1001

#define MAX_PHONE_LEN       16
#define MAX_LOCATION_LEN    32
#define GSM_LINE_LEN        90
#define SMS_TEXT_LEN        180

char alertNumber[MAX_PHONE_LEN] = "+94704775855";
char deviceLocation[MAX_LOCATION_LEN] = "Colombo 01 ABC";

// 1 = line enabled
// 0 = line disabled
bool lineEnable[4] = {1, 0, 0, 1};

// ---------------- EEPROM CONFIG STORAGE ----------------
// STM8S103 data EEPROM starts at 0x4000.
// Saved format: magic + version + number + location + line mask + checksum.
#define CG_EEPROM_BASE_ADDR      0x4000
#define CG_CFG_MAGIC1            0x43    // 'C'
#define CG_CFG_MAGIC2            0x47    // 'G'
#define CG_CFG_VERSION           1

#define CG_CFG_OFF_MAGIC1        0
#define CG_CFG_OFF_MAGIC2        1
#define CG_CFG_OFF_VERSION       2
#define CG_CFG_OFF_NUMBER        3
#define CG_CFG_OFF_LOCATION      (CG_CFG_OFF_NUMBER + MAX_PHONE_LEN)
#define CG_CFG_OFF_MASK          (CG_CFG_OFF_LOCATION + MAX_LOCATION_LEN)
#define CG_CFG_OFF_CHECKSUM      (CG_CFG_OFF_MASK + 4)

// STM8 FLASH / EEPROM control registers
#define CG_FLASH_IAPSR           (*(volatile unsigned char *)0x505F)
#define CG_FLASH_DUKR            (*(volatile unsigned char *)0x5064)
#define CG_FLASH_IAPSR_DUL       0x08

// ---------------- LED LOGIC ----------------
// STM8 onboard LED usually:
// LOW  = LED ON
// HIGH = LED OFF
#define LED_ON   LOW
#define LED_OFF  HIGH

// ---------------- MAIN STATES ----------------
#define STATE_GSM_AT_CHECK       0
#define STATE_GSM_NET_CHECK      1
#define STATE_SMS_TEXT_MODE      2
#define STATE_SMS_RECEIVE_MODE   3
#define STATE_RUN                4
#define STATE_SMS_WAIT_PROMPT    5
#define STATE_SMS_WAIT_RESULT    6

byte deviceState = STATE_GSM_AT_CHECK;

// ---------------- HEALTH CHECK STATES ----------------
#define HEALTH_IDLE      0
#define HEALTH_WAIT_AT   1
#define HEALTH_WAIT_NET  2

byte healthState = HEALTH_IDLE;

// ---------------- TIMINGS ----------------
#define AT_RETRY_TIME          3000
#define NET_RETRY_TIME         5000
#define CMD_RETRY_TIME         3000

#define HEALTH_CHECK_TIME      10000
#define HEALTH_REPLY_TIMEOUT   3000

#define SMS_PROMPT_TIMEOUT     8000
#define SMS_SEND_TIMEOUT       20000
#define SMS_MAX_RETRY          2
#define SMS_RETRY_DELAY        15000

unsigned long lastATSendTime = 0;
unsigned long lastNetSendTime = 0;
unsigned long lastCmdSendTime = 0;
unsigned long smsStartTime = 0;

unsigned long lastHealthCheckTime = 0;
unsigned long healthStartTime = 0;
unsigned long lastSmsFailTime = 0;

unsigned long lastLedTime = 0;
bool ledState = false;

// ---------------- GSM STATUS ----------------
bool gsmAtOK = false;
bool gsmNetOK = false;
bool smsTextModeOK = false;
bool smsReceiveModeOK = false;

// ---------------- OPTO STATES ----------------
bool optoState[4];
bool alertSentForLine[4] = {0, 0, 0, 0};

bool smsPending = false;
bool smsIsAlert = false;
byte smsRetryCount = 0;
bool smsPromptError = false;

// ---------------- GSM BUFFER ----------------
char gsmLine[GSM_LINE_LEN];
int gsmIndex = 0;

char incomingSender[MAX_PHONE_LEN];
bool waitingSmsBody = false;

// ---------------- SMS BUFFER ----------------
char smsText[SMS_TEXT_LEN];
char smsTargetNumber[MAX_PHONE_LEN];

// =====================================================
// SAFE COPY / APPEND
// =====================================================
void safeCopy(char *dst, const char *src, int maxLen) {
  int i = 0;

  while (src[i] && i < maxLen - 1) {
    dst[i] = src[i];
    i++;
  }

  dst[i] = '\0';
}

void safeAppend(char *dst, const char *src, int maxLen) {
  int d = 0;
  int s = 0;

  while (dst[d]) d++;

  while (src[s] && d < maxLen - 1) {
    dst[d] = src[s];
    d++;
    s++;
  }

  dst[d] = '\0';
}

void trimInPlace(char *s) {
  int start = 0;
  int i;
  int end;

  while (s[start] == ' ' || s[start] == '\t' || s[start] == '\r' || s[start] == '\n') {
    start++;
  }

  if (start > 0) {
    i = 0;
    while (s[start]) {
      s[i] = s[start];
      i++;
      start++;
    }
    s[i] = '\0';
  }

  end = 0;
  while (s[end]) end++;

  if (end == 0) return;

  end--;

  while (end >= 0 && (s[end] == ' ' || s[end] == '\t' || s[end] == '\r' || s[end] == '\n')) {
    s[end] = '\0';
    end--;
  }
}

// =====================================================
// VALIDATION
// =====================================================
bool isValidPhone(const char *num) {
  int len = 0;
  int i;

  if (num[0] != '+') return false;

  while (num[len]) len++;

  if (len < 11 || len >= MAX_PHONE_LEN) return false;

  for (i = 1; i < len; i++) {
    if (num[i] < '0' || num[i] > '9') return false;
  }

  return true;
}

bool isValidLineMask(const char *mask) {
  int i;

  for (i = 0; i < 4; i++) {
    if (mask[i] != '0' && mask[i] != '1') {
      return false;
    }
  }

  if (mask[4] != '\0') return false;

  return true;
}

// =====================================================
// OPTO READ
// Correct logic:
// 1 = CUT
// 0 = OK
// =====================================================
void readOptos() {
  optoState[0] = digitalRead(PC3);  // Line 1
  optoState[1] = digitalRead(PC4);  // Line 2
  optoState[2] = digitalRead(PC5);  // Line 3
  optoState[3] = digitalRead(PC6);  // Line 4
}

// =====================================================
// SMS TEXT BUILD
// =====================================================
void addLineStatus(int lineIndex) {
  if (lineIndex == 0) safeAppend(smsText, "Line 1 - ", SMS_TEXT_LEN);
  if (lineIndex == 1) safeAppend(smsText, "Line 2 - ", SMS_TEXT_LEN);
  if (lineIndex == 2) safeAppend(smsText, "Line 3 - ", SMS_TEXT_LEN);
  if (lineIndex == 3) safeAppend(smsText, "Line 4 - ", SMS_TEXT_LEN);

  if (!lineEnable[lineIndex]) {
    safeAppend(smsText, "Disabled\r\n", SMS_TEXT_LEN);
  } else if (optoState[lineIndex]) {
    safeAppend(smsText, "CUT\r\n", SMS_TEXT_LEN);
  } else {
    safeAppend(smsText, "OK\r\n", SMS_TEXT_LEN);
  }
}

void buildAlertSmsText() {
  smsText[0] = '\0';

  safeAppend(smsText, "-- CopperGuard @ ", SMS_TEXT_LEN);
  safeAppend(smsText, deviceLocation, SMS_TEXT_LEN);
  safeAppend(smsText, " --\r\n\r\n", SMS_TEXT_LEN);

  safeAppend(smsText, "Line cut Detected !\r\n\r\n", SMS_TEXT_LEN);

  addLineStatus(0);
  addLineStatus(1);
  addLineStatus(2);
  addLineStatus(3);
}

void buildConfigOkSmsText() {
  smsText[0] = '\0';

  safeAppend(smsText, "Config Updated\r\nNo: ", SMS_TEXT_LEN);
  safeAppend(smsText, alertNumber, SMS_TEXT_LEN);
  safeAppend(smsText, "\r\nLoc: ", SMS_TEXT_LEN);
  safeAppend(smsText, deviceLocation, SMS_TEXT_LEN);
  safeAppend(smsText, "\r\n", SMS_TEXT_LEN);

  for (int i = 0; i < 4; i++) {
    if (i == 0) safeAppend(smsText, "Line 1 - ", SMS_TEXT_LEN);
    if (i == 1) safeAppend(smsText, "Line 2 - ", SMS_TEXT_LEN);
    if (i == 2) safeAppend(smsText, "Line 3 - ", SMS_TEXT_LEN);
    if (i == 3) safeAppend(smsText, "Line 4 - ", SMS_TEXT_LEN);

    if (lineEnable[i]) {
      safeAppend(smsText, "Enabled", SMS_TEXT_LEN);
    } else {
      safeAppend(smsText, "Disabled", SMS_TEXT_LEN);
    }

    if (i < 3) safeAppend(smsText, "\r\n", SMS_TEXT_LEN);
  }
}

void buildConfigErrorSmsText() {
  smsText[0] = '\0';

  safeAppend(smsText, "Cfg Error\r\n+947XXXXXXXX,Location,1001", SMS_TEXT_LEN);
}

// =====================================================
// LED INDICATION
// =====================================================
void setLed(bool on) {
  ledState = on;
  digitalWrite(LED_BUILTIN, on ? LED_ON : LED_OFF);
}

void blinkLed(unsigned int blinkTime) {
  if (millis() - lastLedTime >= blinkTime) {
    lastLedTime = millis();

    ledState = !ledState;

    digitalWrite(LED_BUILTIN, ledState ? LED_ON : LED_OFF);
  }
}

bool anyEnabledLineCut() {
  for (int x = 0; x < 4; x++) {
    if (optoState[x] && lineEnable[x]) {
      return true;
    }
  }

  return false;
}

void updateLedIndicator() {
  // Priority 1: SMS sending / reminder call = blink every 100 ms
  if (deviceState >= STATE_SMS_WAIT_PROMPT) {
    blinkLed(100);
    return;
  }

  // Priority 2: any GSM error / not ready = LED ON
  // This covers AT fail, SIM/network fail, SMS mode fail, and startup/recovery states.
  if (!gsmAtOK || !gsmNetOK || !smsTextModeOK || !smsReceiveModeOK || deviceState != STATE_RUN) {
    setLed(true);
    return;
  }

  // Priority 3: any enabled line is cut = blink every 200 ms
  if (anyEnabledLineCut()) {
    blinkLed(200);
    return;
  }

  // Normal operation heartbeat:
  // LED ON for 100 ms once every 3 seconds.
  if (millis() - lastLedTime >= 3000) {
    lastLedTime = millis();
    setLed(true);
    return;
  }

  if (ledState && millis() - lastLedTime >= 100) {
    setLed(false);
  }
}

// =====================================================
// GSM COMMANDS
// =====================================================
void sendATCommand() {
  Serial_print_s("AT\r\n");
  lastATSendTime = millis();
}

void sendNetworkCheckCommand() {
  Serial_print_s("AT+CREG?\r\n");
  lastNetSendTime = millis();
}

void sendTextModeCommand() {
  Serial_print_s("AT+CMGF=1\r\n");
  lastCmdSendTime = millis();
}

void sendReceiveModeCommand() {
  Serial_print_s("AT+CNMI=2,2,0,0,0\r\n");
  lastCmdSendTime = millis();
}

void startSmsSend(const char *number) {
  safeCopy(smsTargetNumber, number, MAX_PHONE_LEN);

  Serial_print_s("AT+CMGS=\"");
  Serial_print_s(smsTargetNumber);
  Serial_print_s("\"\r\n");

  smsStartTime = millis();
}

void sendSmsBody() {
  Serial_print_s(smsText);
  Serial_write(26);   // Ctrl + Z

  smsStartTime = millis();
}

bool lineIsSmsError();

// =====================================================
// GSM LINE READ
// =====================================================
bool readGsmLine() {
  char c;

  while (Serial_available()) {
    c = Serial_read();

    if (c == '\r') {
      continue;
    }

    if (c == '\n') {
      gsmLine[gsmIndex] = '\0';

      if (gsmIndex > 0) {
        gsmIndex = 0;
        return true;
      }

      gsmIndex = 0;
    } else {
      if (gsmIndex < GSM_LINE_LEN - 1) {
        gsmLine[gsmIndex] = c;
        gsmIndex++;
      }
    }
  }

  return false;
}

bool readSmsPrompt() {
  char c;

  smsPromptError = false;

  while (Serial_available()) {
    c = Serial_read();

    if (c == '>') {
      gsmIndex = 0;
      return true;
    }

    if (c == '\r') {
      continue;
    }

    if (c == '\n') {
      gsmLine[gsmIndex] = '\0';

      if (gsmIndex > 0) {
        trimInPlace(gsmLine);

        if (lineIsSmsError()) smsPromptError = true;
      }

      gsmIndex = 0;
    } else {
      if (gsmIndex < GSM_LINE_LEN - 1) {
        gsmLine[gsmIndex] = c;
        gsmIndex++;
      }
    }
  }

  return false;
}

// =====================================================
// GSM RESPONSE CHECKS
// =====================================================
bool lineIsOK() {
  return strcmp(gsmLine, "OK") == 0;
}

bool lineIsNetworkOK() {
  if (strstr(gsmLine, "+CREG:") != 0) {
    if (strstr(gsmLine, ",1") != 0) return true;
    if (strstr(gsmLine, ",5") != 0) return true;
  }

  return false;
}

bool lineIsSmsError() {
  if (strcmp(gsmLine, "ERROR") == 0) return true;
  if (strstr(gsmLine, "+CMS ERROR") != 0) return true;
  if (strstr(gsmLine, "+CME ERROR") != 0) return true;

  return false;
}

// =====================================================
// INCOMING SMS CONFIGURATION
// =====================================================
bool extractQuotedNumber(const char *line, char *out) {
  int firstQ = -1;
  int secondQ = -1;
  int i;
  int j;

  for (i = 0; line[i]; i++) {
    if (line[i] == '"') {
      if (firstQ < 0) {
        firstQ = i;
      } else {
        secondQ = i;
        break;
      }
    }
  }

  if (firstQ < 0 || secondQ < 0 || secondQ <= firstQ + 1) {
    out[0] = '\0';
    return false;
  }

  j = 0;

  for (i = firstQ + 1; i < secondQ && j < MAX_PHONE_LEN - 1; i++) {
    out[j] = line[i];
    j++;
  }

  out[j] = '\0';

  return true;
}

void resetAlertFlags() {
  for (int i = 0; i < 4; i++) {
    alertSentForLine[i] = false;
  }
}

// =====================================================
// EEPROM CONFIG SAVE / LOAD
// =====================================================
unsigned char eepromReadByte(unsigned int offset) {
  return *((volatile unsigned char *)(CG_EEPROM_BASE_ADDR + offset));
}

bool eepromUnlock() {
  unsigned long startTime;

  if (CG_FLASH_IAPSR & CG_FLASH_IAPSR_DUL) {
    return true;
  }

  startTime = millis();

  CG_FLASH_DUKR = 0xAE;
  CG_FLASH_DUKR = 0x56;

  while (!(CG_FLASH_IAPSR & CG_FLASH_IAPSR_DUL)) {
    if (millis() - startTime > 100) {
      return false;
    }
  }

  return true;
}

void eepromLock() {
  CG_FLASH_IAPSR &= (unsigned char)(~CG_FLASH_IAPSR_DUL);
}

void eepromWriteByte(unsigned int offset, unsigned char value) {
  volatile unsigned char *addr;

  if (eepromReadByte(offset) == value) {
    return;
  }

  addr = (volatile unsigned char *)(CG_EEPROM_BASE_ADDR + offset);
  *addr = value;

  // Small wait for STM8 EEPROM byte programming.
  delay(5);
}

unsigned char calcConfigChecksum(const char *number, const char *location, const char *mask) {
  unsigned int sum = 0;
  int i;

  sum += CG_CFG_VERSION;

  for (i = 0; number[i]; i++) {
    sum += (unsigned char)number[i];
  }

  for (i = 0; location[i]; i++) {
    sum += (unsigned char)location[i];
  }

  for (i = 0; i < 4; i++) {
    sum += (unsigned char)mask[i];
  }

  return (unsigned char)(sum & 0xFF);
}

void buildLineMask(char *mask) {
  mask[0] = lineEnable[0] ? '1' : '0';
  mask[1] = lineEnable[1] ? '1' : '0';
  mask[2] = lineEnable[2] ? '1' : '0';
  mask[3] = lineEnable[3] ? '1' : '0';
  mask[4] = '\0';
}

void saveConfigToEEPROM() {
  char mask[5];
  unsigned char checksum;
  int i;

  buildLineMask(mask);
  checksum = calcConfigChecksum(alertNumber, deviceLocation, mask);

  if (!eepromUnlock()) {
    return;
  }

  eepromWriteByte(CG_CFG_OFF_MAGIC1, CG_CFG_MAGIC1);
  eepromWriteByte(CG_CFG_OFF_MAGIC2, CG_CFG_MAGIC2);
  eepromWriteByte(CG_CFG_OFF_VERSION, CG_CFG_VERSION);

  for (i = 0; i < MAX_PHONE_LEN; i++) {
    eepromWriteByte(CG_CFG_OFF_NUMBER + i, (unsigned char)alertNumber[i]);
  }

  for (i = 0; i < MAX_LOCATION_LEN; i++) {
    eepromWriteByte(CG_CFG_OFF_LOCATION + i, (unsigned char)deviceLocation[i]);
  }

  for (i = 0; i < 4; i++) {
    eepromWriteByte(CG_CFG_OFF_MASK + i, (unsigned char)mask[i]);
  }

  eepromWriteByte(CG_CFG_OFF_CHECKSUM, checksum);

  eepromLock();
}

bool loadConfigFromEEPROM() {
  char savedNumber[MAX_PHONE_LEN];
  char savedLocation[MAX_LOCATION_LEN];
  char savedMask[5];
  unsigned char savedChecksum;
  unsigned char calcChecksum;
  int i;

  if (eepromReadByte(CG_CFG_OFF_MAGIC1) != CG_CFG_MAGIC1) return false;
  if (eepromReadByte(CG_CFG_OFF_MAGIC2) != CG_CFG_MAGIC2) return false;
  if (eepromReadByte(CG_CFG_OFF_VERSION) != CG_CFG_VERSION) return false;

  for (i = 0; i < MAX_PHONE_LEN; i++) {
    savedNumber[i] = (char)eepromReadByte(CG_CFG_OFF_NUMBER + i);
  }
  savedNumber[MAX_PHONE_LEN - 1] = '\0';

  for (i = 0; i < MAX_LOCATION_LEN; i++) {
    savedLocation[i] = (char)eepromReadByte(CG_CFG_OFF_LOCATION + i);
  }
  savedLocation[MAX_LOCATION_LEN - 1] = '\0';

  for (i = 0; i < 4; i++) {
    savedMask[i] = (char)eepromReadByte(CG_CFG_OFF_MASK + i);
  }
  savedMask[4] = '\0';

  savedChecksum = eepromReadByte(CG_CFG_OFF_CHECKSUM);
  calcChecksum = calcConfigChecksum(savedNumber, savedLocation, savedMask);

  if (savedChecksum != calcChecksum) return false;
  if (!isValidPhone(savedNumber)) return false;
  if (savedLocation[0] == '\0') return false;
  if (!isValidLineMask(savedMask)) return false;

  safeCopy(alertNumber, savedNumber, MAX_PHONE_LEN);
  safeCopy(deviceLocation, savedLocation, MAX_LOCATION_LEN);

  lineEnable[0] = savedMask[0] == '1';
  lineEnable[1] = savedMask[1] == '1';
  lineEnable[2] = savedMask[2] == '1';
  lineEnable[3] = savedMask[3] == '1';

  resetAlertFlags();

  return true;
}

bool applyConfigSms(char *body) {
  char *comma1;
  char *comma2;

  char *newNumber;
  char *newLocation;
  char *newMask;

  trimInPlace(body);

  comma1 = strchr(body, ',');
  if (comma1 == 0) return false;

  comma2 = strchr(comma1 + 1, ',');
  if (comma2 == 0) return false;

  comma1[0] = '\0';
  comma2[0] = '\0';

  newNumber = body;
  newLocation = comma1 + 1;
  newMask = comma2 + 1;

  trimInPlace(newNumber);
  trimInPlace(newLocation);
  trimInPlace(newMask);

  if (!isValidPhone(newNumber)) return false;
  if (newLocation[0] == '\0') return false;
  if (!isValidLineMask(newMask)) return false;

  safeCopy(alertNumber, newNumber, MAX_PHONE_LEN);
  safeCopy(deviceLocation, newLocation, MAX_LOCATION_LEN);

  lineEnable[0] = newMask[0] == '1';
  lineEnable[1] = newMask[1] == '1';
  lineEnable[2] = newMask[2] == '1';
  lineEnable[3] = newMask[3] == '1';

  resetAlertFlags();
  saveConfigToEEPROM();

  return true;
}

bool handleIncomingSmsLine() {
  trimInPlace(gsmLine);

  if (gsmLine[0] == '\0') {
    return true;
  }

  // Incoming SMS header
  if (strncmp(gsmLine, "+CMT:", 5) == 0) {
    extractQuotedNumber(gsmLine, incomingSender);
    waitingSmsBody = true;
    return true;
  }

  // Incoming SMS body
  if (waitingSmsBody) {
    waitingSmsBody = false;

    // Security: only the currently registered alert number can update config.
    // Unknown numbers are ignored without reply.
    if (strcmp(incomingSender, alertNumber) != 0) {
      return true;
    }

    if (applyConfigSms(gsmLine)) {
      buildConfigOkSmsText();
    } else {
      buildConfigErrorSmsText();
    }

    // Send config result only to the registered sender.
    safeCopy(smsTargetNumber, incomingSender, MAX_PHONE_LEN);
    smsIsAlert = false;
    smsRetryCount = 0;
    smsPending = true;

    return true;
  }

  return false;
}

// =====================================================
// CONTINUOUS GSM HEALTH CHECK
// =====================================================
void serviceGsmHealthCheck() {
  if (healthState == HEALTH_IDLE) {
    if (millis() - lastHealthCheckTime >= HEALTH_CHECK_TIME) {
      sendATCommand();

      healthState = HEALTH_WAIT_AT;
      healthStartTime = millis();
      lastHealthCheckTime = millis();
    }

    return;
  }

  if (healthState == HEALTH_WAIT_AT) {
    if (readGsmLine()) {
      if (handleIncomingSmsLine()) return;

      if (lineIsOK()) {
        gsmAtOK = true;

        sendNetworkCheckCommand();

        healthState = HEALTH_WAIT_NET;
        healthStartTime = millis();
        return;
      }
    }

    if (millis() - healthStartTime >= HEALTH_REPLY_TIMEOUT) {
      gsmAtOK = false;
      gsmNetOK = false;
      smsTextModeOK = false;
      smsReceiveModeOK = false;

      healthState = HEALTH_IDLE;
      deviceState = STATE_GSM_AT_CHECK;
    }

    return;
  }

  if (healthState == HEALTH_WAIT_NET) {
    if (readGsmLine()) {
      if (handleIncomingSmsLine()) return;

      if (lineIsNetworkOK()) {
        gsmNetOK = true;
        healthState = HEALTH_IDLE;
        return;
      }

    }

    if (millis() - healthStartTime >= HEALTH_REPLY_TIMEOUT) {
      gsmNetOK = false;
      smsTextModeOK = false;
      smsReceiveModeOK = false;

      healthState = HEALTH_IDLE;
      deviceState = STATE_GSM_NET_CHECK;
    }

    return;
  }
}

// =====================================================
// LINE CUT CHECK
// =====================================================
void checkLineCuts() {
  bool needSms = false;

  readOptos();

  for (int i = 0; i < 4; i++) {
    if (!lineEnable[i]) {
      alertSentForLine[i] = false;
      continue;
    }

    if (!optoState[i]) {
      alertSentForLine[i] = false;
      continue;
    }

    if (optoState[i] && !alertSentForLine[i]) {
      needSms = true;
    }
  }

  if (needSms && !smsPending) {
    if (millis() - lastSmsFailTime >= SMS_RETRY_DELAY) {
      buildAlertSmsText();
      safeCopy(smsTargetNumber, alertNumber, MAX_PHONE_LEN);
      smsIsAlert = true;
      smsRetryCount = 0;
      smsPending = true;
    }
  }
}

// =====================================================
// TRY SEND PENDING SMS
// =====================================================
void servicePendingSms() {
  if (!smsPending) return;

  if (!gsmAtOK || !gsmNetOK || !smsTextModeOK || !smsReceiveModeOK) {
    return;
  }

  if (healthState != HEALTH_IDLE) {
    return;
  }

  startSmsSend(smsTargetNumber);
  deviceState = STATE_SMS_WAIT_PROMPT;
}

void handleSmsFailure() {
  gsmAtOK = false;
  gsmNetOK = false;
  smsTextModeOK = false;
  smsReceiveModeOK = false;

  lastSmsFailTime = millis();

  smsRetryCount++;

  if (smsRetryCount >= SMS_MAX_RETRY) {
    smsPending = false;
    smsIsAlert = false;
    smsRetryCount = 0;
  }

  deviceState = STATE_GSM_AT_CHECK;
}

void markCurrentCutsAsAlerted() {
  readOptos();

  for (int i = 0; i < 4; i++) {
    if (lineEnable[i] && optoState[i]) {
      alertSentForLine[i] = true;
    }
  }
}
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
void loop() {
  serviceStateMachine();
  updateLedIndicator();
}

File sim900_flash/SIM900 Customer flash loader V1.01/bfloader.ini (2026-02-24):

[flashloader_config]
version=Simcom - sim900 Customer flash loader V1.01
number_of_target=13
current_target=12
enable_trace_debug=0
enable_trace_time=1
enable_com_log=0
[target#00]
target_name=PCF5213-3C/D
target_id=1
ext_loader=0
ext_loader_type=0
bypass_security=0
target_usb=0
ext_ibt=0
loader_id=133
loader_file=
app_file=
upload_file=
partition_file=
partition_path=
ibt_file=
user_passwd=es
secure_chip=0
synchro_mode=0
customer_id=0x0
cid_specify=0
cur_memory=2
loader_memory=3
ebi_address=0x30000000
ebi_value=0x1
otp_address=0x0
cgu_address=0x0
cgu_pll_disable=0x0
cgu_pll_enable=0x0
signature_length=0x10
signature_return=0x10
stop_point=0
[target#00_scenario_config]
cmd_type=0x7
wait_after_dwl=0
jump_delay=0
upload_offset=0x0
upload_length=0x0
burn_otp=0
otpreg_value00=0x0
otpreg_value01=0x0
otpreg_value02=0x0
otpreg_value03=0x0
otpreg_value04=0x0
otpreg_value05=0x0
otpreg_value06=0x0
otpreg_value07=0x0
otpreg_value08=0x0
otpreg_value09=0x0
otpreg_value10=0x0
otpreg_value11=0x0
otpreg_value12=0x0
otpreg_value13=0x0
otpreg_value14=0x0
otpreg_value15=0x0
[target#00_scenario_config_erase_config]
option=1
offset=0x0
length=0x0
[target#00_link_BR_dflt]
type=1
port=1
baudrate=2
databit=3
parity=2
stopbit=0
ctrlflow=0
[target#00_link_LD_dflt]
type=1
port=1
baudrate=2
databit=3
parity=2
stopbit=0
ctrlflow=0
[target#00_link_BR_user]
type=1
port=1
baudrate=4
databit=3
parity=2
stopbit=0
ctrlflow=0
[target#00_link_LD_user]
type=1
port=1
baudrate=4
databit=3
parity=2
stopbit=0
ctrlflow=0
[target#00_memory_device_scram]
location_name=SCRAM
base_address=0xC000000
erase_time=700
[target#00_memory_device_user]
location_name=User Defined
base_address=0x10000000
erase_time=700
[target#00_memory_device_0]
location_name=CS0
base_address=0x10000000
erase_time=700
[target#00_memory_device_1]
location_name=CS1
base_address=0x18000000
erase_time=700
[target#00_memory_device_2]
location_name=CS2
base_address=0x20000000
erase_time=700
[target#00_memory_device_3]
location_name=CS3
base_address=0x24000000
erase_time=700
[target#00_memory_device_4]
location_name=NAND_FLASH
base_address=0x10000000
erase_time=700
[target#00_memory_device_5]
location_name=SDI
base_address=0x20000000
erase_time=700
[target#01]
target_name=PCF5213-3E/F/H/I
target_id=2
ext_loader=0
ext_loader_type=0
bypass_security=0
target_usb=0
ext_ibt=0
loader_id=133
loader_file=
app_file=
upload_file=
partition_file=
partition_path=
ibt_file=
user_passwd=es
secure_chip=0
synchro_mode=0
customer_id=0x0
cid_specify=0
cur_memory=2
loader_memory=3
ebi_address=0x30000000
ebi_value=0x1
otp_address=0x0
cgu_address=0x0
cgu_pll_disable=0x0
cgu_pll_enable=0x0
signature_length=0x10
signature_return=0x10
stop_point=0
[target#01_scenario_config]
cmd_type=0x7
wait_after_dwl=0
jump_delay=0
upload_offset=0x0
upload_length=0x0
burn_otp=0
otpreg_value00=0x0
otpreg_value01=0x0
otpreg_value02=0x0
otpreg_value03=0x0
otpreg_value04=0x0
otpreg_value05=0x0
otpreg_value06=0x0
otpreg_value07=0x0
otpreg_value08=0x0
otpreg_value09=0x0
otpreg_value10=0x0
otpreg_value11=0x0
otpreg_value12=0x0
otpreg_value13=0x0
otpreg_value14=0x0
otpreg_value15=0x0
[target#01_scenario_config_erase_config]
option=1
offset=0x0
length=0x0
[target#01_link_BR_dflt]
type=1
port=1
baudrate=4
databit=3
parity=2
stopbit=0
ctrlflow=0
[target#01_link_LD_dflt]
type=1
port=1
baudrate=4
databit=3
parity=2
stopbit=0
ctrlflow=0
[target#01_link_BR_user]
type=1
port=1
baudrate=4
databit=3
parity=2
stopbit=0
ctrlflow=0
[target#01_link_LD_user]
type=1
port=1
baudrate=4
databit=3
parity=2
stopbit=0
ctrlflow=0
[target#01_memory_device_scram]
location_name=SCRAM
base_address=0xC000000
erase_time=700
[target#01_memory_device_user]
location_name=User Defined
base_address=0x10000000
erase_time=700
[target#01_memory_device_0]
location_name=CS0
base_address=0x10000000
erase_time=700
[target#01_memory_device_1]
location_name=CS1
base_address=0x18000000
erase_time=700
[target#01_memory_device_2]
location_name=CS2
base_address=0x20000000
erase_time=700
[target#01_memory_device_3]
location_name=CS3
base_address=0x24000000
erase_time=700
[target#01_memory_device_4]
location_name=NAND_FLASH
base_address=0x10000000
erase_time=700
[target#01_memory_device_5]
location_name=SDI
base_address=0x20000000
erase_time=700
[target#02]
target_name=PNX5230_1A
target_id=3
ext_loader=0
ext_loader_type=0
bypass_security=0
target_usb=0
ext_ibt=0
loader_id=156
loader_file=
app_file=
upload_file=
partition_file=
partition_path=
ibt_file=
user_passwd=es
secure_chip=0
synchro_mode=0
customer_id=0x0
cid_specify=0
cur_memory=2
loader_memory=3
ebi_address=0x50000000
ebi_value=0x1
otp_address=0x5040C048
cgu_address=0x50500004
cgu_pll_disable=0x6F0D005D
cgu_pll_enable=0x6F0C005D
signature_length=0x10
signature_return=0x10
stop_point=0
[target#02_scenario_config]
cmd_type=0x7
wait_after_dwl=0
jump_delay=0
upload_offset=0x0
upload_length=0x0
burn_otp=0
otpreg_value00=0x0
otpreg_value01=0x0
otpreg_value02=0x0
otpreg_value03=0x0
otpreg_value04=0x0
otpreg_value05=0x0
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

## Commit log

2026-02-24 documentation update
    [Cable_Theft_Priority_vs_Incidents.xlsx, Copper_Guard_Timeline.xlsx, Reported Cable Theft Incidents - Last 03 months_sorted_by_length.xlsx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]
2026-06-15 Update copperguard_v5.ino
    Added call function + current number only updates (access control) + heartbeat LED
2026-07-08 images Updated
    [BOM_STM-final.csv, PickAndPlace_PCB_STM-final.csv]
